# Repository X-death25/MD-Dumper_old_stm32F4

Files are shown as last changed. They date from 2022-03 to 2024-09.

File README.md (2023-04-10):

# MD-Dumper

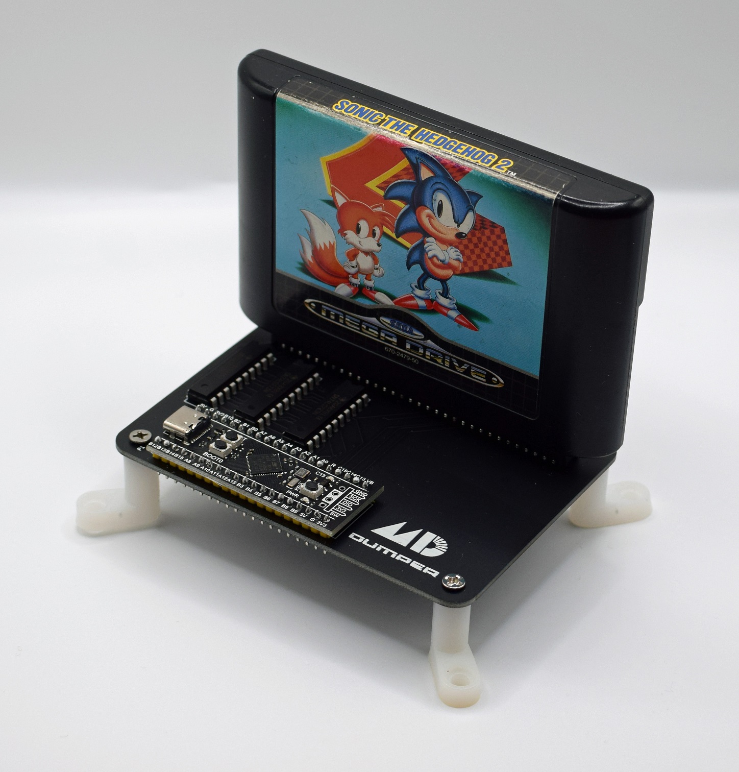
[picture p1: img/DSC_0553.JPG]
MD_pcb
 

What is it ?
-----

MD Dumper is an USB Sega Megadrive cartridge Dumper : <br>
Hardware is based on STM32F4 (BluePillV2) : STM32F4x1 MiniF4 https://github.com/WeActTC/MiniSTM32F4x1  <br>
New version also add some developpement feature witch can be usefull for Megadrive developper.  <br>

Feature :
-----

Firmware Version : 2.0

Software Version : 2.0

| Feature | Implemented |
| --- | --- |
| ROM Dump up to 16 MEG  Classic | :white_check_mark: |
| ROM Dump up to 32 MEG  Bankswitch | :white_check_mark: |
| SRAM Backup Memory Classic | :white_check_mark: |
| SRAM Backup Memory Bankswitch | :white_check_mark: |
| Rewrite Krikzz flashkit cart or compatible  | :white_check_mark: |

How to use it ?
-----

You just need an USB-C to USB. <br>
Connect the dumper to the PC and wait blue led activation. Insert game cartridge.  <br>
Start the software. Enjoy ! <br>

Operating System Compatibility
-----

Microsoft Windows 10

Where i can buy it ?
-----

https://www.tindie.com/products/xdeath/md-dumper-usb-megadrive-cartridge-readerwriter/

Linked Repositories
-----

My other projects related to Megadrive Hardware/Software developpement

-=Python MD-Dumper GUI=-
Easy and multiplateform GUI for MD-Dumper <br>
https://github.com/X-death25/PyMD-Dumper

-=DMC Direct Megadrive Connection=-
SGDK lib for bi-directionnal communication between Megadrive and PC <br>
*Coming Soon*

-=SMD_01=-
Simple 5V TTL 8MB Rewritable cartridge for testing code on real hardware <br>
*Coming Soon*

-=X-Flash=-
Altera EPM240 CPLD based Megadrive cartridge used for advanced research <br>
https://github.com/X-death25/X-Flash

Need Help ?
-----
If you need help or want to improvite or report a bug youre welcome to the official MD Dumper Discord !
https://discord.gg/8AtuA29Dnw

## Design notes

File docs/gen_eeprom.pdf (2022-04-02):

Serial EEPROM emulation

Serial EEPROM devices are present in a few Sega Genesis cartridges and used as external Backup RAM. As you will later see, they can NOT be emulated as usual parallel SRAM and also use various modes depending on their memory size. Most Genesis/Megadrive emulators out there does not emulate those custom devices, resulting in various glitches (beside the fact that saving game data is impossible) in games that rely on this.

Here are some links to datasheets for each kind of EEPROM types for those who couldn’t understand my bad english ;)

### 24C01(mode1) : http://www.icmic.com/datasheets/X24C01.pdf

24C01-24C16(mode2) :

### http://www.atmel.com/dyn/resources/prod_documents/doc0180.pdf

### 24C64 (mode3):http://www.phys.hawaii.edu/~bryce/component_data/24LC65-ISM.pdf

Basically, the protocol used so that the Main CPU (68000), considered as MASTER device, can communicate with the serial EEPROM (considered as SLAVE device), could be summarized this way:

•SLAVE is controlled by the MASTER using two serial lines:

o/SDA is the DATA line, used to send/receive data (READ/WRITE)
o/SCL is the CLOCK line used to manage the clock cycles (WRITE ONLY)

Each line is mapped in the 68000 address space at a specific addres, at one specific bit position (see various used mappers in game database) and can have LOW (bit=0) or HIGH (bit=1) state.

•A clock cycle starts by a transition of /SCL from LOW to HIGH and ends by a transition of /SCL from HIGH to LOW. This is used by the MASTER to indicate when /SDA state refers to a new valid DATA bit (received or sent).

•MASTER and SLAVE devices communicate through 8-bits DATA word, which require 8 clock cycles. The 9th cycle is called the ACK cycle where the receiver (SLAVE or MASTER, depending on the current operation) must send an acknowledge to the sender by setting /SDA line LOW during this cycle, when it is ready to receive more data.

•Each READ or WRITE operation must be initiated by the MASTER with a START condition and terminated with a STOP condition:

oSTART condition is set when /SDA is changed from HIGH to LOW while /SCL remains HIGH
oSTOP condition is set when /SDA is changed from LOW to HIGH while /SCL remains HIGH

•After the START condition, depending on the EEPROM mode, the MASTER immediately send one or more 8-bit words to specify the address that should be later read or written. There are 3 known EEPROM modes:

oMode 1 (24C01 only) have a maximal size of 128bytes (7 bits address) and need only one address word. The 7 first bits set the memory address to be read/write and the 8th bit set the operation type (READ or WRITE)

oMode 2 (24C01 to 24C16) can have up to 8 devices linked together, with a maximal size of 2 Kbytes (11 bits address max.), which means one 24C16, two 24C08, four 24C04 or eight 24C02/24C01 :

the 1st word has 4 fixed bits, then 3bits setting the device address and/or eventually the upper bits of the memory address to read/write (24C04-24C16). The 8th bit set the type of the operation (READ or WRITE).

the 2
nd word set the lower bits of the memory address to read/write (only 7bits for 24C01 in mode 2, because it’s only 128 bytes wide)

oMode 3 (24C32 and more) work like Mode 2 excepted that the maximal address size is 64 Kbytes (max. 16 bits address) per device (a maximum of eight devices can be linked with no size restriction).

the 1st word is like in the previous mode, excepted bits d3-d1 always set the device address (0-7). Last bit always set the operation type.

the 2
nd word set the upper bits of the memory address to read/write (the number of bits depends on the memory size)

the 3rd word set the eight lower bits of the memory address to read/write.

NB: In modes 2 and 3, before a READ operation, only the 1st word is actually sent, the EEPROM contains an address counter that saves the address of the next word to be accessed (incremented from a previous READ or WRITE operation, as stated below)

•After a WRITE operation has been initiated, the MASTER will send one or more 8bits DATA words through the /SDA line. After each written word, the EEPROM must send a ACK and increment the address for the next data word to be written. The address will roll up to base memory address when maximal writepage size has been reached. If the MASTER send a STOP condition, the WRITE operation ends, otherwise the WRITE operation continues to next address.

•After a READ operation has been initiated, the MASTER will read one or more 8bits DATA words through the /SDA line. After each received word, the MASTER will send a ACK and the EEPROM will increment the address of the next data word to be read. The address will roll up to 0 when maximal memory size has been reached. If the MASTER does not send a ACK during the 9th cycle, the READ operation ends and the EEPROM waits for STOP condition, otherwise, the READ operation continues to next address.

This is pretty how eeprom’s access are emulated in Genesis Plus (see eeprom.c for more details). Thanks a lot to 8bitwizard from spriteminds.net forums who initially give me indications about the various EEPROM types and mappers used in Sega Genesis games.

Following is a game database of Sega Genesis games that I found using serial EEPROM, listed by companies (as they usually use specific company mappers).Their specific caracteristics (mappers, mode, size,...) are also mentionned, deducted from various testings.

Feel free to use these informations and my sourcecode in your own project.

EkeEke (July 2007)

ACCLAIM (81)

NBA Jam (UE)(J)

T-081326, T-81033
header OK ($200001-$200001)

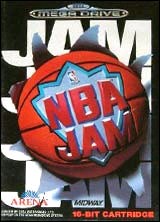
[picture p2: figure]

MODE: 8BITS WORD ADDRESS (MODE2) SIZE_MASK: 0xFF (24C02)
PAGE_MASK: 0x03
SDA_IN : 0x200001 (bit 0)
SDA_OUT: 0x200001 (bit 1)
SCL : 0x200001 (bit 1)

NB: this game uses a different EEPROM mapper than any other Acclaim games. Also it uses 16-bits write & read to access EEPROM.

Blockbuster World Video Game Championship II (U) NBA Jam Tournament Edition (UE)(J)

T-81406, T-81143
header KO

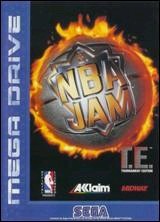
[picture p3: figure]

MODE: 8BITS WORD ADDRESS (MODE2) SIZE_MASK: 0xFF (24C02)
PAGE_MASK: 0x03
SDA_IN : 0x200001 (bit 0)
SDA_OUT: 0x200001 (bit 0)
SCL : 0x200000 (bit 0)

NB: Rev 00 of the game has buggy eeprom support, only Rev01 version will correctly save game data.

NFL Quarterback Club (JUE)

T-081276
header OK ($200000-$200001)

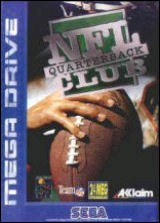
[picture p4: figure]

MODE: 8BITS WORD ADDRESS (MODE2) SIZE_MASK: 0xFF (24C02)
PAGE_MASK: 0x03
SDA_IN : 0x200001 (bit 0)
SDA_OUT: 0x200001 (bit 0)
SCL : 0x200000 (bit 0)

NFL Quarterback Club 96 (UE)

T-081586
header OK ($200000-$200001)

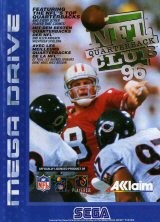
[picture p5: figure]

MODE: 8BITS WORD ADDRESS (MODE2) SIZE_MASK: 0x7FF (24C16)
PAGE_MASK: 0x07
SDA_IN : 0x200001 (bit 0)
SDA_OUT: 0x200001 (bit 0)
SCL : 0x200000 (bit 0)

College Slam (U)

T-81576
header OK ($200001-$200001)

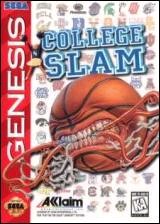
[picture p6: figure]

MODE: 16BITS WORD ADDRESS (MODE3) SIZE_MASK: 0x1FFF (24C64)
PAGE_MASK: 0x07
SDA_IN : 0x200001 (bit 0)
SDA_OUT: 0x200001 (bit 0)
SCL : 0x200000 (bit 0)

Frank Thomas Big Hurt Baseball (UE)

T-81476
header OK ($200000-$200001)

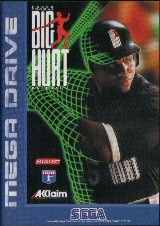
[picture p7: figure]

MODE: 16BITS WORD ADDRESS (MODE3) SIZE_MASK: 0x1FFF (24C64)
PAGE_MASK: 0x07
SDA_IN : 0x200001 (bit 0)
SDA_OUT: 0x200001 (bit 0)
SCL : 0x200000 (bit 0)

ELECTRONIC ARTS (12)

NHLPA Hockey 93 (UE)

T-50396
header KO

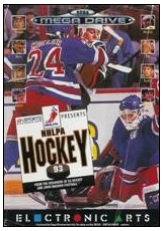
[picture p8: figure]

MODE: 7BITS WORD ADDRESS (MODE1) SIZE_MASK: 0x7F (24C01)
PAGE_MASK: 0x03
SDA_IN : 0x200001 (bit 7)
SDA_OUT: 0x200001 (bit 7)
SCL : 0x200001 (bit 6)

Rings of Power (UE)

T-50176
header KO

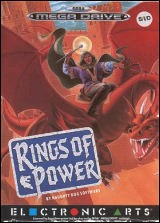
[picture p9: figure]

MODE: 7BITS WORD ADDRESS (MODE1) SIZE_MASK: 0x7F (24C01)
PAGE_MASK: 0x03
SDA_IN : 0x200001 (bit 7)
SDA_OUT: 0x200001 (bit 7)
SCL : 0x200001 (bit 6)

These two games use 16-bits write & read to access EEPROM.

SEGA

Evander 'Real Deal' Holyfield's Boxing (UE)(J)

MK-1215, G-4084
header OK ($200001-$200001)

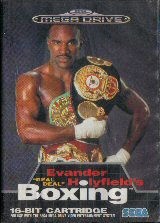
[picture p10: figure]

MODE: 7BITS WORD ADDRESS (MODE1) SIZE_MASK: 0x7F (24C01)
PAGE_MASK: 0x03
SDA_IN : 0x200001 (bit 0)
SDA_OUT: 0x200001 (bit 0)
SCL : 0x200001 (bit 1)

Greatest Heavyweights of the Ring (J)(U)(E)

G-5538, MK-1228, PR-1993
header OK ($200001-$200001)

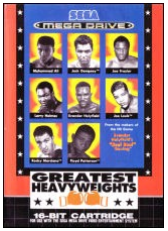
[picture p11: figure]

MODE: 7BITS WORD ADDRESS (MODE1) SIZE_MASK: 0x7F (24C01)
PAGE_MASK: 0x03
SDA_IN : 0x200001 (bit 0)
SDA_OUT: 0x200001 (bit 0)
SCL : 0x200001 (bit 1)

Wonder Boy in Monster World (UE) Wonder Boy V - Monster World III (J)

G-4060
header OK ($200001-$200001)

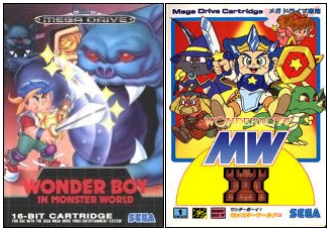
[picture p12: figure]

MODE: 7BITS WORD ADDRESS (MODE1) SIZE_MASK: 0x7F (24C01)
PAGE_MASK: 0x03
SDA_IN : 0x200001 (bit 0)
SDA_OUT: 0x200001 (bit 0)
SCL : 0x200001 (bit 1)

Sports Talk Baseball
00001211-00
header KO

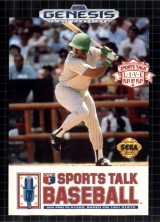
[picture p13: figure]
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

This game uses 16-bits write & read to access EEPROM.

CAPCOM (12)

Megaman - The Wily Wars (E)
Rockman Mega World (J) [alt]

T-12046, T-12053 (checksum = 0xEA80) header OK ($200001-$200001)

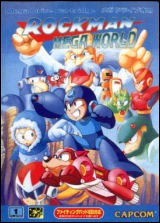
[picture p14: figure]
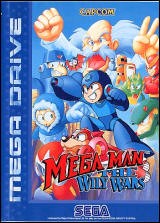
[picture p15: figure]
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

NB: the original version of Rockman Mega World (J) uses traditional SRAM

CODEMASTERS

Micro Machines 2 - Turbo Tournament (E) (J-Cart)

T-120096-50
header KO

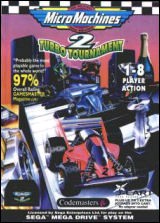
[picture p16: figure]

MODE: 8BITS WORD ADDRESS (MODE2) SIZE_MASK: 0x3FF (24C08)
PAGE_MASK: 0x0F
SDA_IN : 0x300000 (bit 0)
SDA_OUT: 0x380001 (bit 7)
SCL : 0x300000 (bit 1)

NB: this game needs the external RAM to be initialized with 0xFF

Micro Machines Military (E) (J-Cart)

00000000-00 (checksum = 0x168B or 0xCEE0) header KO

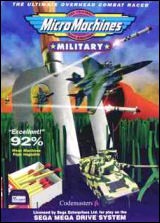
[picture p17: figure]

MODE: 8BITS WORD ADDRESS (MODE2) SIZE_MASK: 0x3FF (24C08)
PAGE_MASK: 0x0F
SDA_IN : 0x300000 (bit 0)
SDA_OUT: 0x380001 (bit 7)
SCL : 0x300000 (bit 1)

Micro Machines Turbo Tournament 96 (E) (J-Cart)

00000000-00 (checksum = 0x165E or 0x2C41) header KO

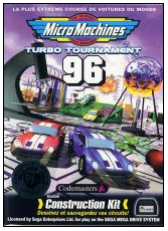
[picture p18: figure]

MODE: 8BITS WORD ADDRESS (MODE2) SIZE_MASK: 0x7FF (24C16)
PAGE_MASK: 0xF
SDA_IN : 0x300000 (bit 0)
SDA_OUT: 0x380001 (bit 7)
SCL : 0x300000 (bit 1)

Brian Lara Cricket 96
Shane Warne Cricket

T-120146-50
header KO

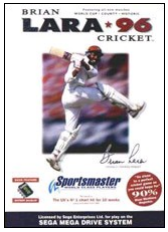
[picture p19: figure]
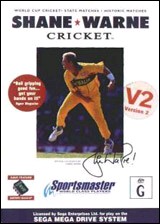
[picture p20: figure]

MODE: 16BITS WORD ADDRESS (MODE3) SIZE_MASK: 0x1FFF (24C64)
PAGE_MASK: ?
SDA_IN : 0x300000 (bit 0)
SDA_OUT: 0x380001 (bit 7)
SCL : 0x300000 (bit 1)

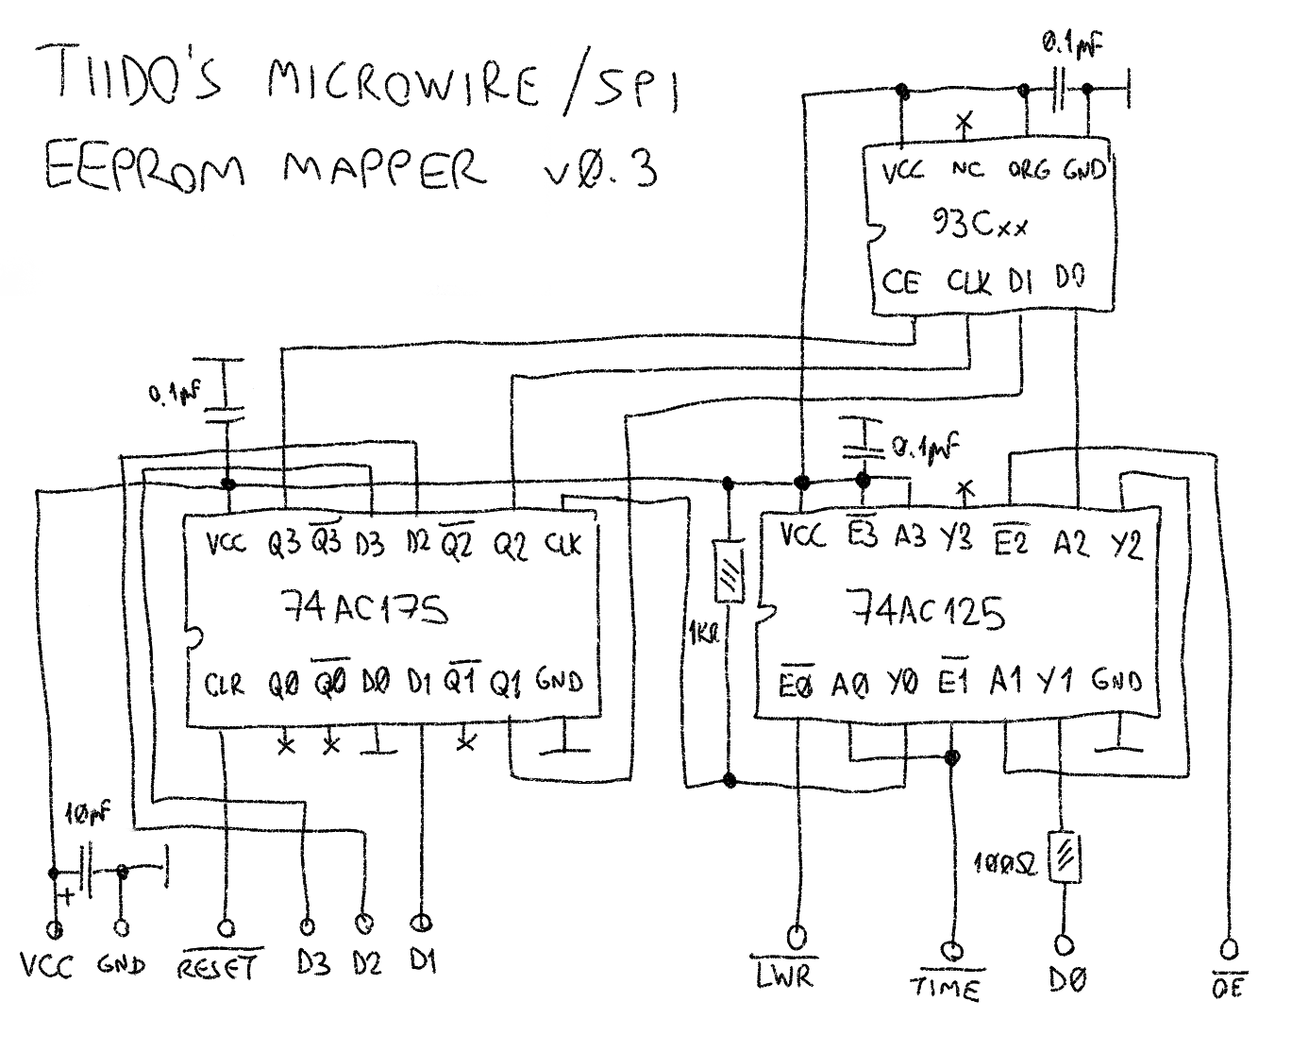
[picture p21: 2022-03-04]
docs/Sega Cartridges/TiidosMicrowireSPImapperForMD.png

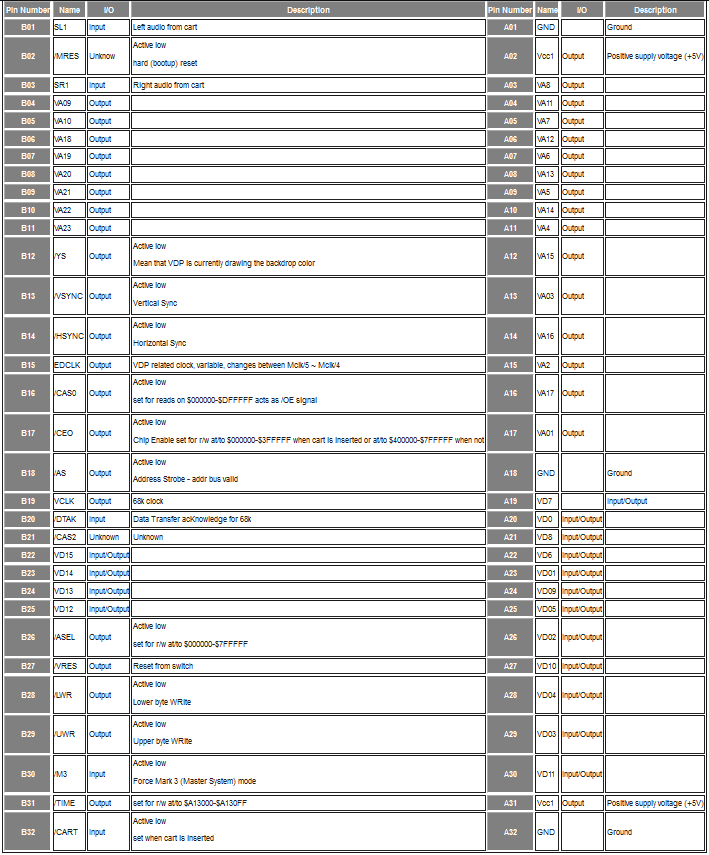
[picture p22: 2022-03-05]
docs/Cartridge Connector MD_Mode.PNG

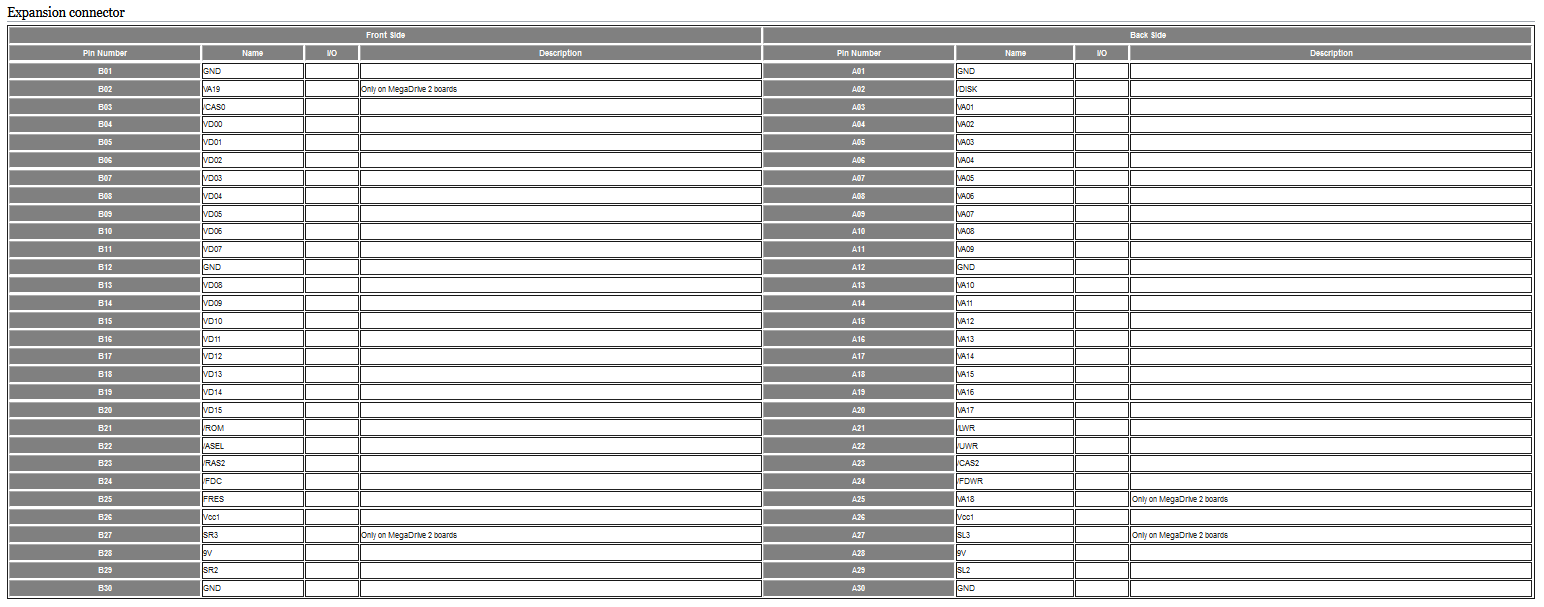
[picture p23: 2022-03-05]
docs/Cartridge Connector EXP_Mode.PNG

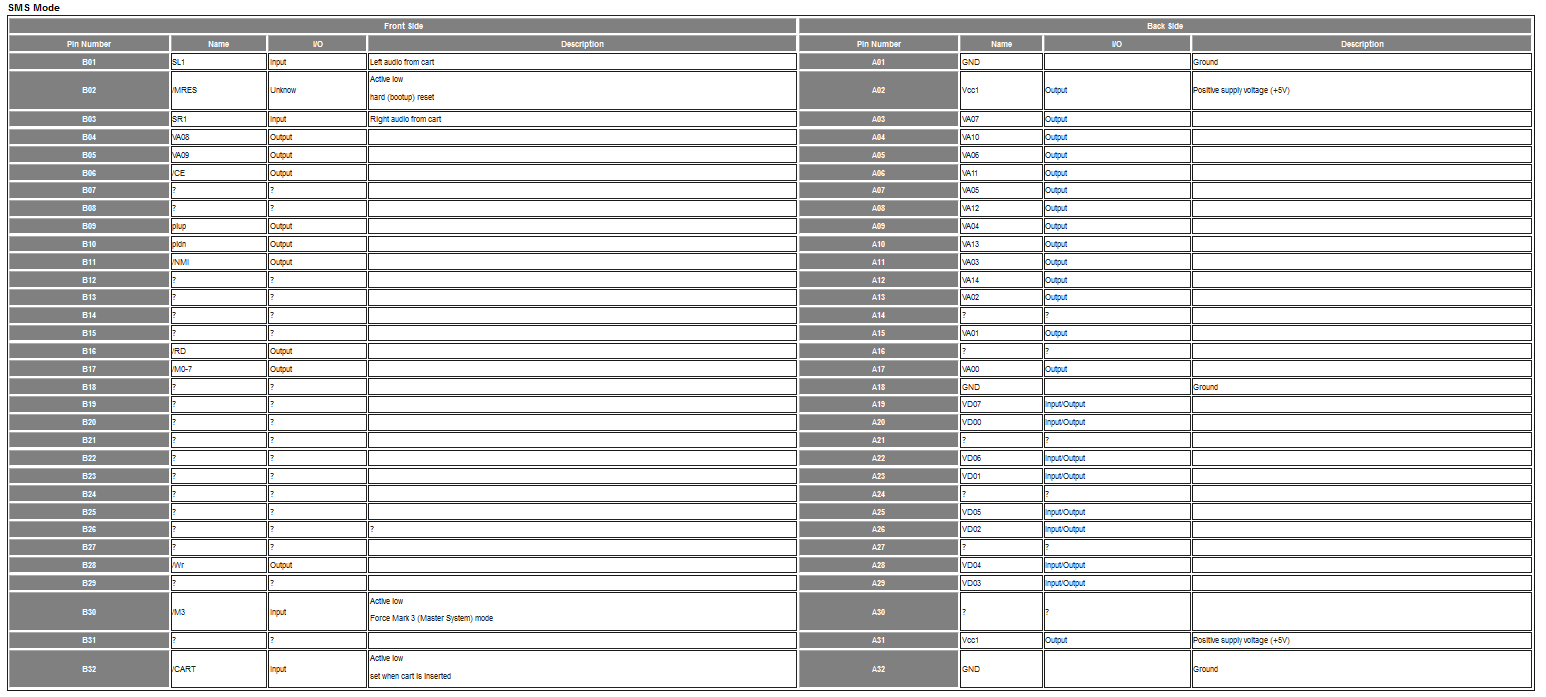
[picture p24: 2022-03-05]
docs/Cartridge Connector SMS_Mode.PNG

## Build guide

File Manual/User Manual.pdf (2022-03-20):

## MD DUMPER

# USB Reader-Flasher Megadrive

F I R S T P U B L I C R E L E A S E 1 2 / 2 0 1 9 | A C T U A L R E L E A S E | V 2 .1 | 0 3 / 2 0 2 2

## Version

2.1

# This product is an unofficial and unlicensed hardware release for the SEGA Mega Drive console, and is not affiliated with SEGA Enterprises Ltd, SEGA

Corporation, or SEGA Holdings Co.

# SEGA® and MEGA DRIVE are trademarks

of SEGA Holdings Co.

# Table of Contents

### Product Feature | 4 Installation | 5

Microsoft Windows | 5
GNU Linux | 6
MAC OS X | 6

### How to Dump your games | 7

Games Meta-Informations | 8
Automatic Mode | 9
Manual Mode | 10

### Save Management | 11

Supported Save type SRAM/Serial EEPROM | 11
Emulator Compatibility | 11
Backup a save from Cartridge to PC | 12
Restore a save from PC to Cartridge | 13

### Flashing an home-made cartridge | 14

Flash Memory Detection | 14
Flash Memory Erase | 15
Flash Memory Write | 16
Extra Hardware Support | 17
Sega Lock-ON | 14
Sega 315-5779 ( Super Street Fighter 2 Classic 40 Meg ) | 14
SSF2 Extended ( Overdrive / Sonic 2 Delta 64 Meg) | 14
SSF2 Full ( Demon Of Asteborg 128 Meg) | 14
Watermelon Mapper | 14
DMC : Direct Megadrive Connection | 14
Firmware Upgrade | 18
Notes | 19

## Chapter

0

1

# Product Feature

## - Read Sega Megadrive cartridge up to 128 Meg

## - Support Bankswitch for ROM & Saves

## - Manage / Backup / Restore your own saves

## - Reflash Third-Party Cartridges

## -Read Master System / Mark III Games

## -Support official Sega Mapper ( SSF2 / Lock-ON / VR)

## -Support Third-Party / Homebrew Mapper

## -Realtime Debug Sega Megadrive <> PC ( DMC )

## -Universal Serial Bus USB-C Power & Use

## -Multi OS compatibility Windows/Linux/Mac

## -Open Source Software

## -Open Source Pyhton GUI

## Chapter

1

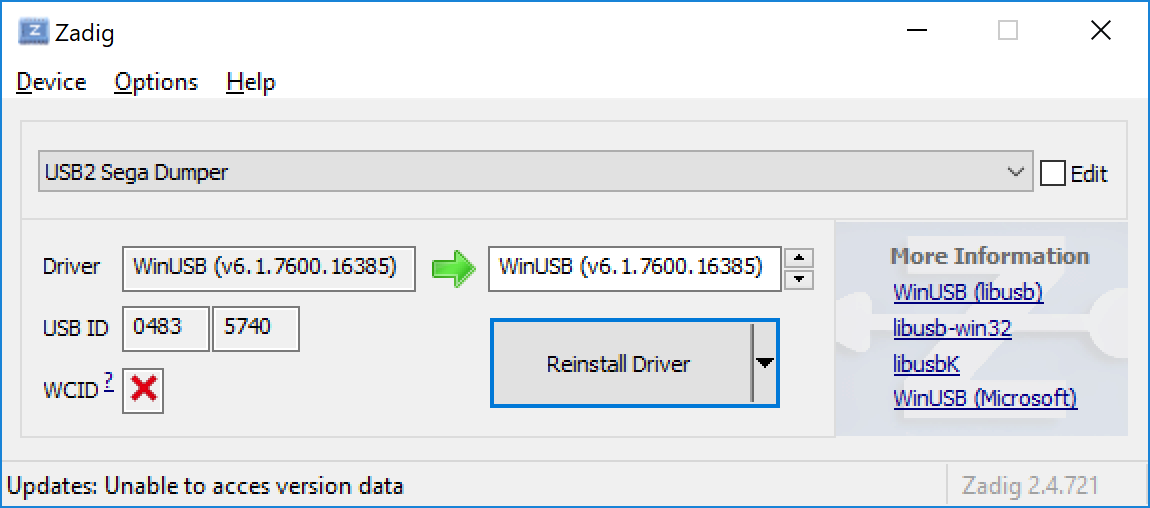
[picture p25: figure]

2

# Installation

## Microsoft Windows :

-Download Lastest release for Windows in the Github (https://github.com/X-death25/MD-Dumper) and extract it in a new or any folder

-Plug the USB Cable

-Wait for Windows automatic hardware installation

-Launch USB View ( in the tools folder)

if everything is ok you should see USB2 Sega Dumper and it's informations

if you see a yellow warning that's mean no driver is currently attached to Sega Dumper so you must use Zadig to force WinUSB driver to Sega Dumper.

https://zadig.akeo.ie/

-After first installation process just do a simple reset by pressing reset button on the board.

-You can launch & use MD Dumper

## Chapter

2

3

## GNU Linux :

-Download Lastest release for Linux in the Github (https://github.com/X-death25/MD-Dumper) and extract it in a new or any folder

-Plug the USB Cable

-You could open a terminal and enter dmesg command for checking installation

if everything is ok you must see these lines

-Enter sudo ./Sega_Dumper for Launch & Use.

## MAC OS X :

/* Todo */

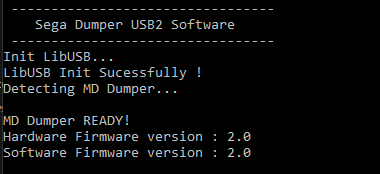
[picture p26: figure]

4

# How to Dump your games

Before dump your game cartridge be sure MD dumper is deconnected and both cartridge slot and game slot is clean.

You can clean it with isopropyl alcohol if needed.

Plug the USB-C to USB cable in the connector and on your PC.

The status led must be following this order :

-RED power led ON

-BLUE access led ON after 3 seconds

When blue led is ON you can insert your game cartridge.

If you put your game cartridge before power on MD dumper you can have some trouble with bus conflict , you can see that with access led blinking.

You can now start MD dumper software.

Both firmware and software version will be displayed at the top in the init hardware sequence.

## Chapter

3

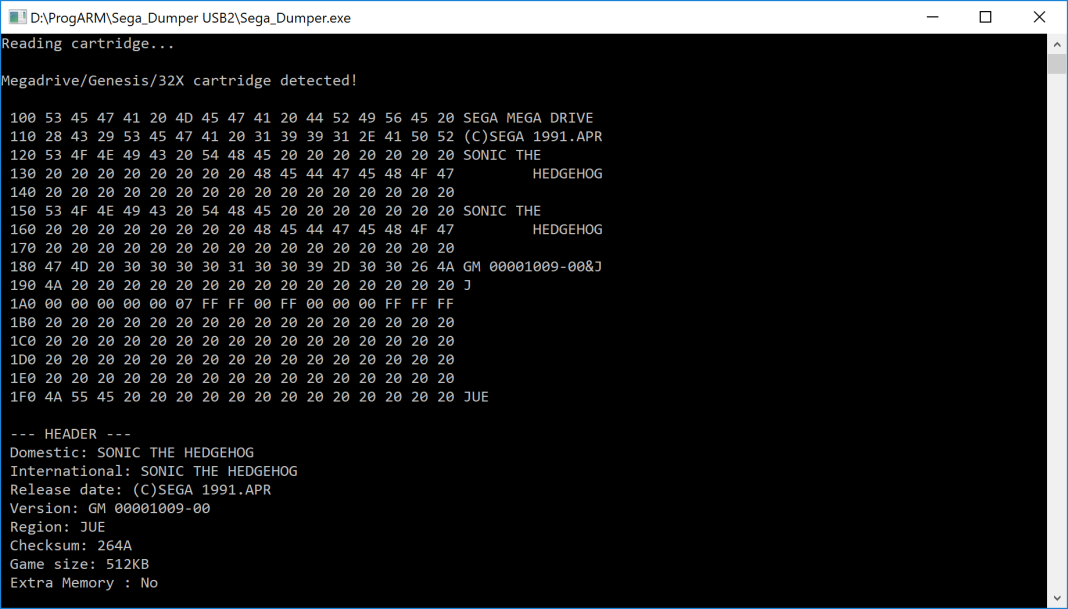
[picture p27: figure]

5

## Games Meta-Informations

The software will start by checking Sega security code and displaying some cartridge informations stored in the beginning of the romchip.

If you cartridge is dirty or damaged Sega security code may not be readed and an error message will be displayed.

The same error message is displayed for a formatted flash cartridge.

In the header parts you can read a summary of all the useful information.
The game and ram size are automatically registered in software so you can use these later for automatic dump mode.
if the game have no backup ram ( like sonic 1 ) you will not see ram info

You can now use the first option of the menu for start a ROM Dump

If you want to read some unofffical games witch don’t use correct information on Metadata you can use the manual dumping mode and specifiy the size of the output dumped file.

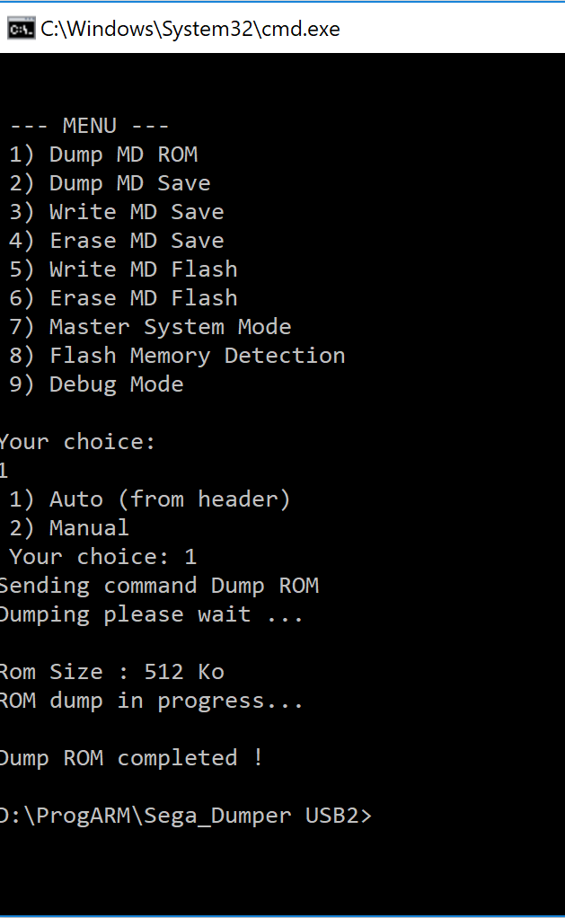
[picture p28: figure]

6

## Dump ( Automatic Mode )

Automatic mode will directly dump the game.
The size of the output file is taken from game meta information.
After dump is completed a file called dump_smd.bin is created.
The created file is generated in an emulator friendly format ( Endianness is reversed ) You can directly launch it in your emulator.

You must reset the board by pressing the push button( reset button) near USB connector for doing another dump ( or unplug – plug the USB )

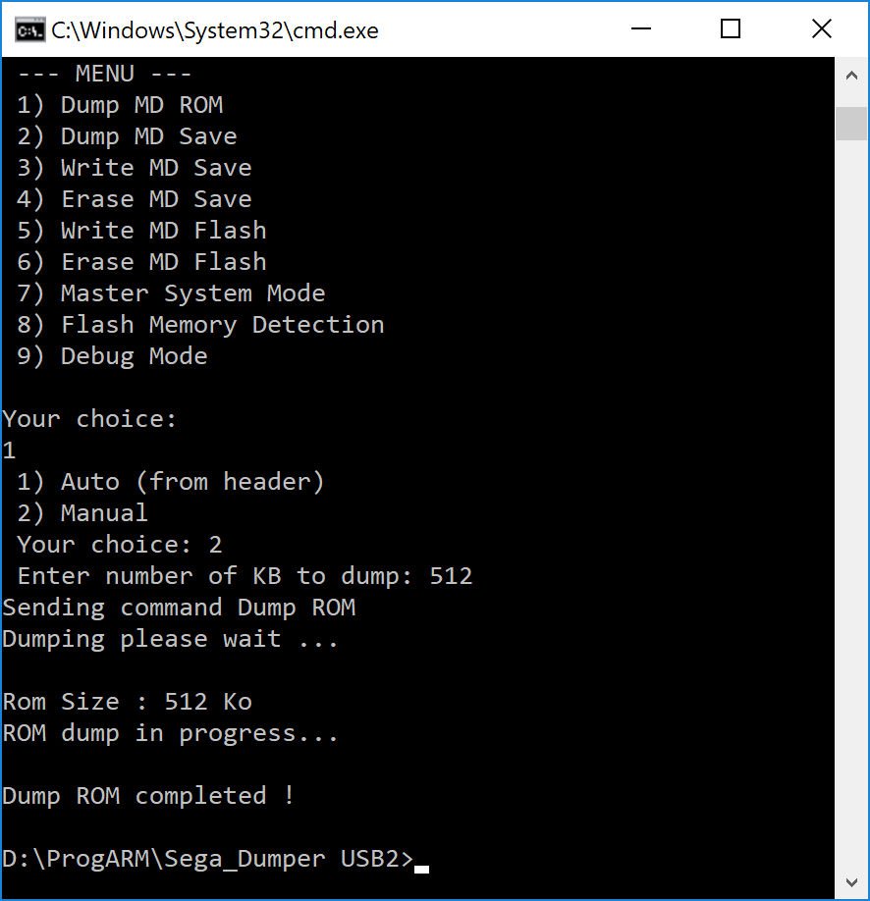
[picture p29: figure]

7

## Dump ( Manual Mode )

Manual mode will dump the game at the specified size.
If the game is smaller than specified size it will be mirrored.
If the game is bigger than specified size you will miss data.
After dump is completed a file called dump_smd.bin is created.

Every official game has correct Meta information so you should only use this mode for homebrew.

MD Dumper support Bankswitch mode so if the game size is more than 16 MEG and have backup ram it will be correctly dumped even in Automatic mode.

8

# SaveManagement

## Supported Save type SRAM / Serial EEPROM

Sega Megadrive cartridge use two different technologies for storing user data

1) Classic parallel 5V SRAM technology + CRC battery for power it when console is turned OFF
- Logic chip for SRAM/ROM access
- CRC Battery
- SRAM chip ( 8k or 32k)
- SRAM power regulator
- ROM chip

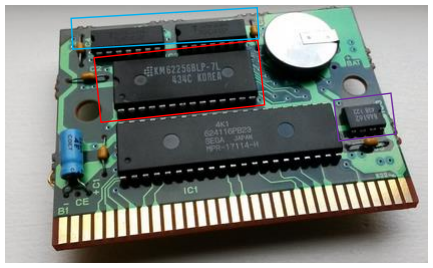
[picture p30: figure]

2) Serial EEPROM I²C/Microwire/SPI
- Logic chip for EEPROM/ROM access
- EEPROM chip
- ROM chip

## Chapter

4

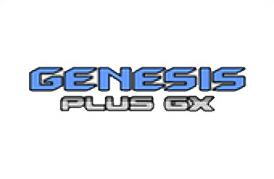
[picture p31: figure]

9

## Emulator Compatibility

The supported emulator is Genesis Plus GX .this emulator has accurate emulation and 100% compatibility even for unofficial games.

You could use your favorite emulator for launch dumped games but the save format used by MD dumper is same as Genesis Plus GX format ( raw 16 bits).

You can start a game in your console , dump the save with MD Dumper and continue your adventure in emulator or reflash your progress in the cartrigde.

Some games use serial EEPROM as backup ram.
You can find a list here :
https://krikzz.com/pub/support/everdrive-md/v2/gen_eeprom.pdf

Reading backup ram for these games has not currently supported. Maybe in a future software upgrade :)

MD Dumper support Bankswitch mode for save too.
Bankswitch ram games will be correctly dumped without modification.

## Backup a save from Cartridge to PC

Insert your cartridge on the edge slot the stickers must be on the front of the PCB.

Start MD Dumper , you will see some save information extracted from header.

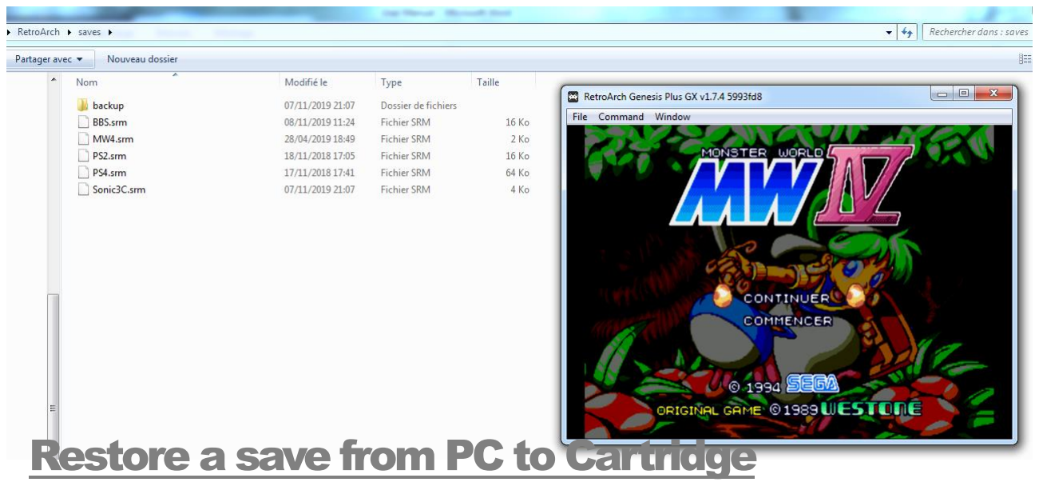
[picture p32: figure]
Restore a save from PC to Cartridge

10

Choose the second menu option : Dump MD Save
like the dump rom option you have multiple dumping mode:

Header information of every official games is correct so you could use automatic mode.
Other mode is for manual mode for specific extra ram size on homebrew PCB. Two files is created :

-dump_smd.srm is the save data in Genesis Plus GX compatible format -raw.srm is an exact dump of the ram chip with no modification.

you just need to copy the dump_smd.srm in the save data of Genesis Plus GX and rename it with the same name of your dumped game.
Forexemple :
MW4.bin for Monster World IV and MW4.srm for save.

Restore or send a save from PC to cartridge is easily as the previous step.

You just need to copy your save file intoMD Dumper folder.

Start MD dumper and choose third option : Write MD Save

write the name of the file with the extension.

for my exemple MW4.srm

ram chip on the cartridge will be fully erased before flash.

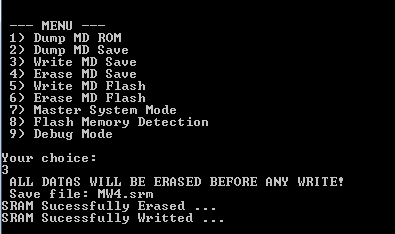
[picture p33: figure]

11

When this step is over you can remove USB cable and plug the cartridge in your console to continue your progress.

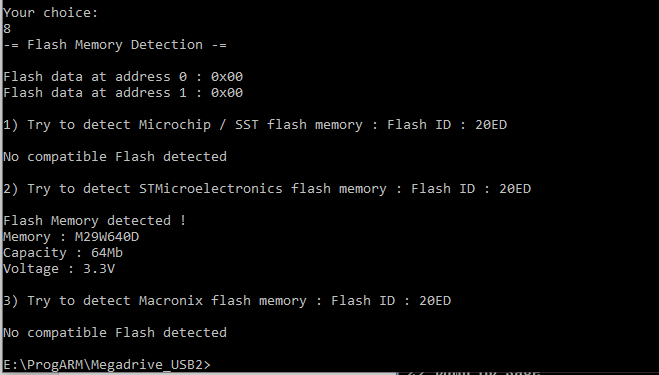
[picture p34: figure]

12

# Flashing an home-made cartridge

## Flash Memory Detection

MD-Dumper support Write Mode for home-made flash based cartridge.

It use the /LWR signal ( pin B28 of the cartridge slot) as /WE signal of flash memory.

First things you could do is try to detect the Manufacturer ID and Chip ID.

Result with M29W640D flash in the Krizz Flash Kit cartridge :

## Chapter

5

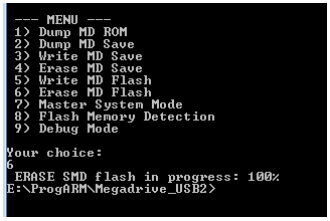
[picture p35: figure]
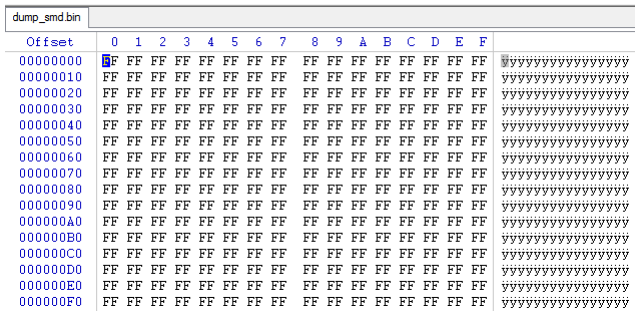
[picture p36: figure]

13

## Flash Memory Erase

Choose option 6 for perform a manually full flash chip Erase.

End of erase will be automatically detected by toggling chip pin.

Time for a complete Erase depends of flash technology (average is less than one minute)

On board Led will be turned "On" when Erase is finished.

MD dumper will check if memory is empty before init a write sequence.

If you dump the flash after an erase you will see only 0xFF bytes/word

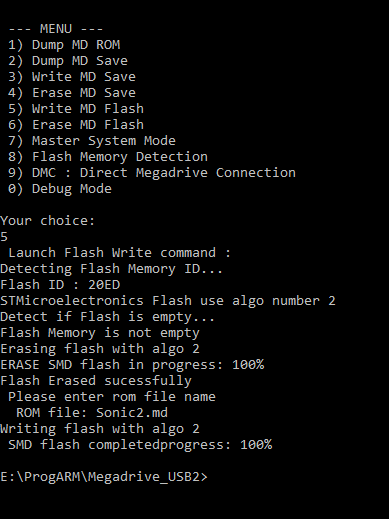
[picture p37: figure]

14

## Flash Memory Write

For sending your game/homebrew copy your file in the same folder of Md dumper

Select option 5 " Write MD Flash " and enter complete name with extension :

1) MD dumper will check if memory is empty before init a write sequence.
2) MD Dumper will check his memory table and select correct flash algo

Speed progress depend of the game size and flash type but average speed is 100 Ko/s.

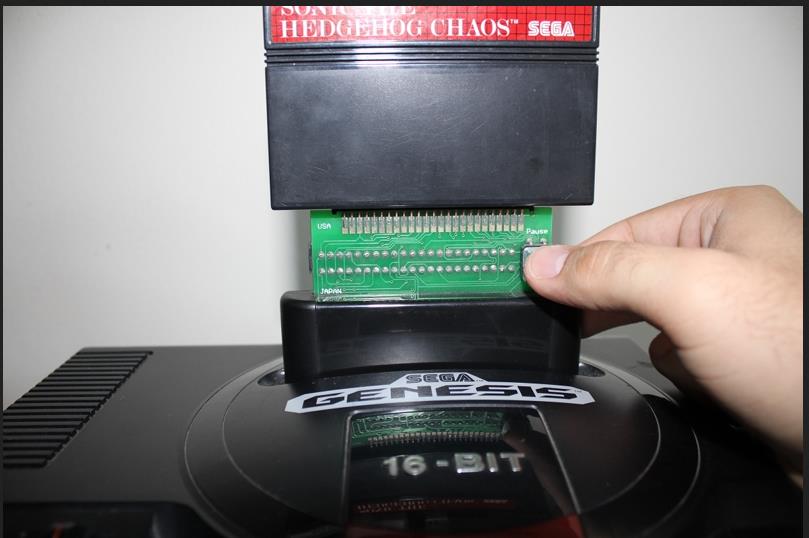
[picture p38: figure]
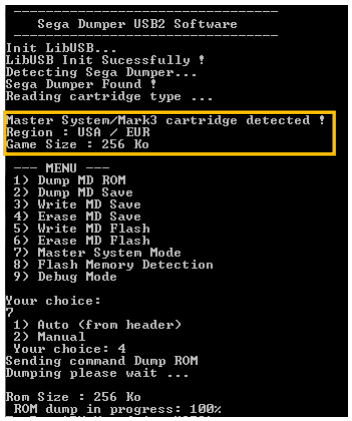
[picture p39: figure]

15

# Master System Compatibility

MD Dumper is also compatible with your Master System / Mark III cartridge.

You can use the Tototek or any compatible Adaptater/Converter.

Just plug the adapter + SMS cartridge and launch MD Dumper you cartridge will be detected directly :

Select option 7 " Master System Mode " and press enter.

After dump is completed a file called dump_sms.sms is created.

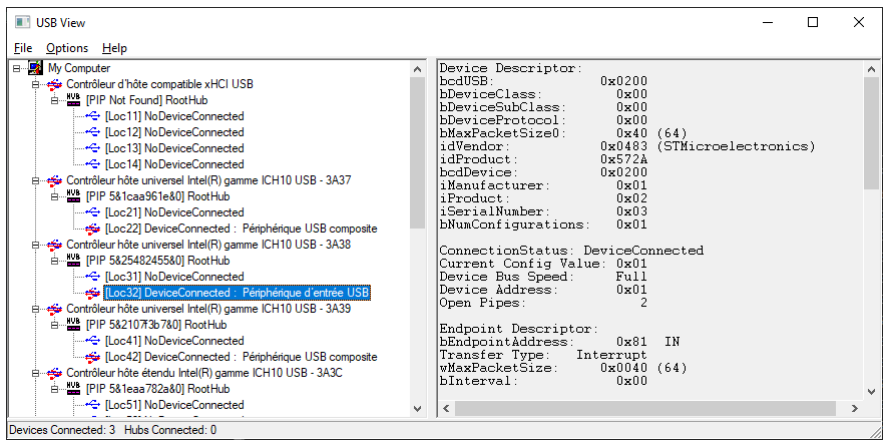
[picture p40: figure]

16

# Firmware Upgrade

MD Dumper New hardware version is based on ARMSTM32F4 so have an embedded bootloader for easy firmware update.

Bootloader is : WeACT HID Bootloader (https://github.com/WeActTC/WeAct_HID_Bootloader_F4x1)

For starting board in update mode you just need to press Keybutton for 2 seconds and press Reset.

Wait 2 seconds, release both button and MD Dumper should start in bootloader mode.

In bootloader mode you can see the LED blinking in progressive mode.

You also can see the USB bootloader mode with Usbview tools

Now you can make a folder with all the file of the Lastest release version in the

MD Dumper Github Firmware Release (https://github.com/X-death25/MD-Dumper/tree/main/Firmware/Lastest)

## Chapter

6

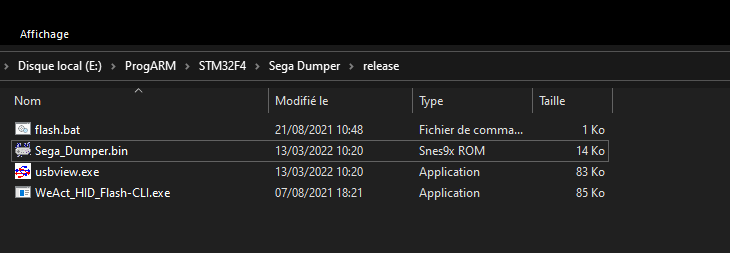
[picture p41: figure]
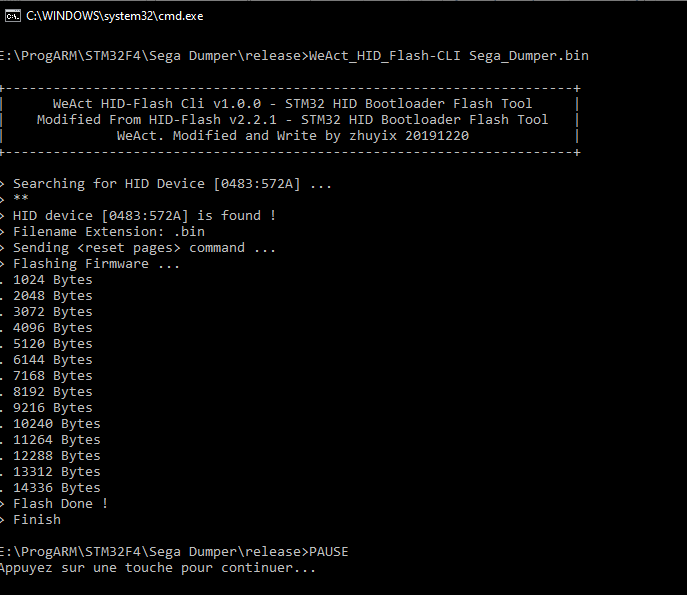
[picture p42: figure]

17

-Sega_Dumper.bin is the ARM compiled code for the STM32

-WeACT_HID_Flash-CLI is bootloader tools for flashing binary

-usbview can help you to view all USB connection of your PC and attached peripherals

-flash.bat is the automatic script for flash binary (call HID flash with Sega_Dumper.bin)

You just need to run cmd script flash.bat :

STM32F4 MD-Dumper code is now successfully updated.

18

# Extra Hardware

## Sega LOCK-ON

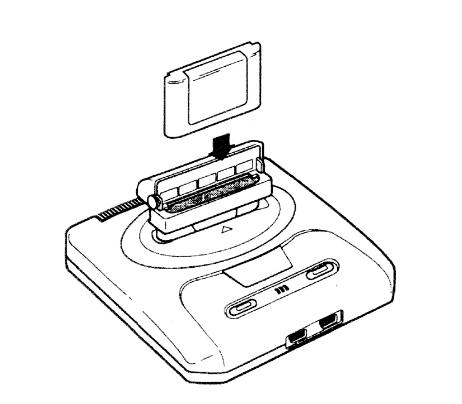
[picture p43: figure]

MD dumper new hardware revision support Sonic & Knuckles SEGA LOCK-ON technology.

Now you can :

-dump Sonic & Knuckles ( Sonic & Knuckles cartridge only)

-dump Blue Sphere ( Sonic & Knuckles + Sonic 1 or Tanglewood)

-dump Sonic 2 & Knuckles ( Sonic & Knuckles + Sonic 2 cartridge)

-dump Sonic 3 & Knuckles ( Sonic & Knuckles + Sonic 3 cartridge)

## Chapter

7

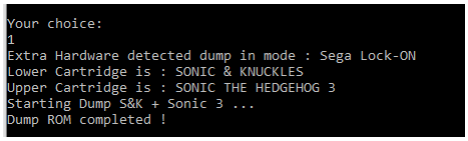
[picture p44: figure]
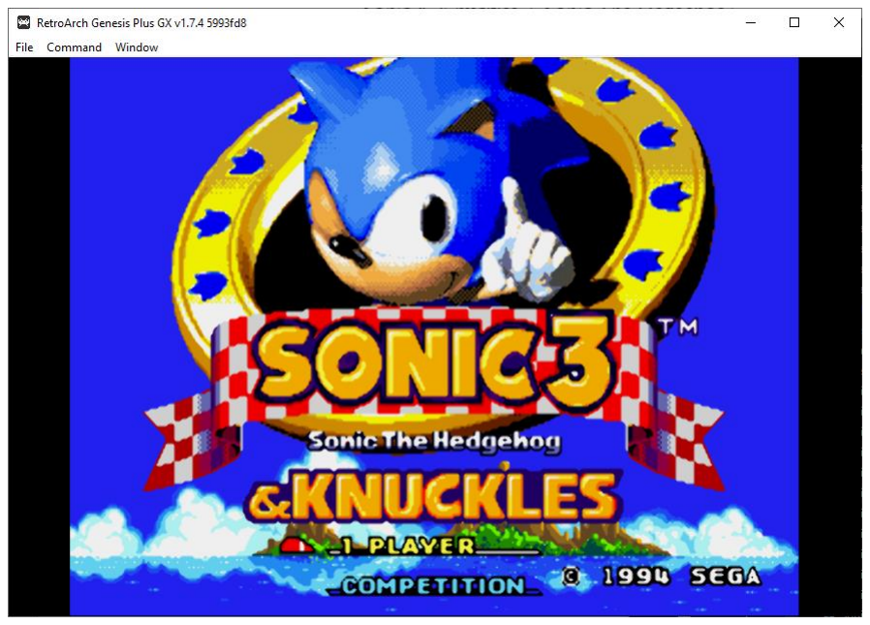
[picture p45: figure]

19

Just select option 1 DUMP ROM and both cartridge UP and LOW should be detected.

If not be sure to clean it properly.

When dump is completed a file will be created in the same folder of Sega Dumper.exe

Possible result is :

Sonic & Knuckles + Sonic The Hedgehog.bin

Sonic & Knuckles + Sonic The Hedgehog2.bin

Sonic & Knuckles + Sonic The Hedgehog3.bin

Be sure to use a compatible emulator for running these game not all emulator support LOCK-ON for storing save.

Note : In the current release ( V2.1) dump save in LOCK-ON mode is not supported yet.

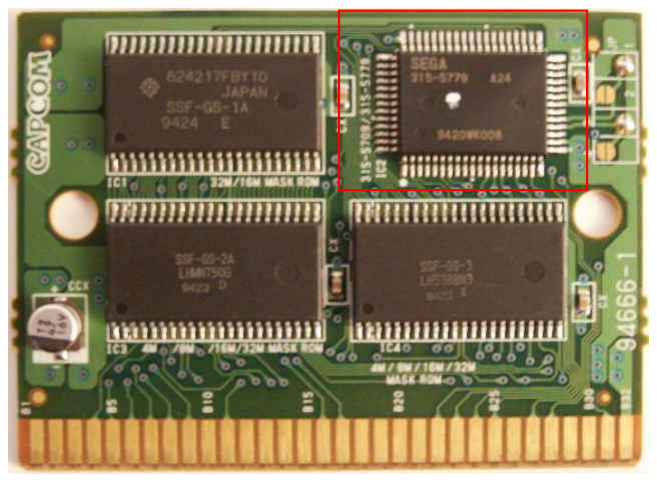
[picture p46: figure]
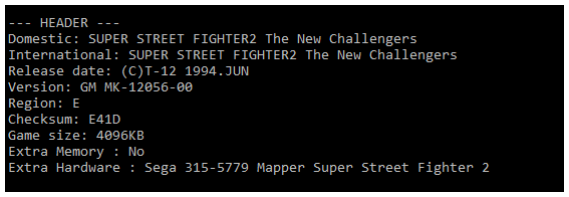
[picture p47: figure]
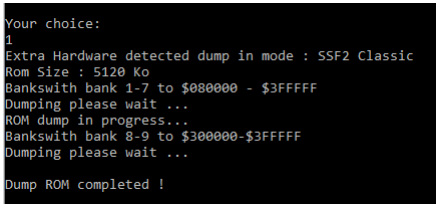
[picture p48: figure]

20

## Sega 315-5779 ( Super Street Fighter 2 )

Sega 315-5779 is the special Sega chip in the game Super Street Fighter 2.

This game use it for store ROM up to 40 Meg.

You can see correct Extra Hardware detection in ROM information:

Header of the game specify a 32Meg cartridge but result is the full 40 Meg data.

Just selection option 1 DUMP ROM and dump will start in SSF2 classic mode

You can find a 40 Meg / 5120 Ko dump_smd.bin ROM Dump

21

## SSF2 Extended

/* To Do*/

Some Homebrew use same bankswitch code as SSF2 for make bigger ROM.

Exemple : Titan Overdrive 2 and Sonic 2 Delta….

MD dumper support this feature, you just need to have SEGA SSF at 0x100 in your rom Header.

22

## SSF2 Full

SSF2 Full is the Sega 315-5779 used at full capacity : 512 Meg ROM + SRAM.

At this time only Demon Of Asterborg use that.

For use MD Dumper in this mode be sure to have SEGA DOA at 0x100

## Virtua Racing

/* To Do*/

## Watermelon Mapper

/* To Do*/

## DMC : Direct Megadrive Connection

/* To Do*/

23

# Release Notes

-13/03/2022 : Add DMC support + Acclaim EEPROM

-18/02/2022 : Second Hardware version release ( ARM STM32F4)

-01/06/2021 : Electronic component shortages -_-‘

-29/12/2019 : First Public Release ( ARM STM32F1 )

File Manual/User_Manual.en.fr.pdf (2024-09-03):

# Version

2.1

# BENNE MD

# Lecteur-Flasher USB Megadrive

PREMIÈRE SORTIE PUBLIQUE 1 2 / 2 0 1 9 | SORTIE RÉELLE | V2. 1 | 0 3 / 2 0 2 2

Traduit de Anglais vers Français - www.onlinedoctranslator.com (https://www.onlinedoctranslator.com/fr/)

# Ce produit est une version matérielle non officielle et sans licence pour la console SEGA Mega Drive, et n'est pas affilié à SEGA

Enterprises Ltd, SEGA.
Corporation, ou SEGA Holdings Co.

# SEGA® et MEGA DRIVE sont des marques

commerciales de SEGA Holdings Co.

0

# Chapitre

# Table des matières

## Caractéristique du produit | 4

# Installation | 5

## Microsoft Windows | 5

## GNU-Linux | 6

## MAC OS X | 6

## Comment vider vos jeux | 7

## Méta-informations sur les jeux | 8 Mode automatique | 9

## Mode manuel | dix

# Gestion des sauvegardes | 11

## Type de sauvegarde pris en charge SRAM/EEPROM série | 11

## Compatibilité de l'émulateur | 11

Sauvegarder une sauvegarde de la cartouche sur le PC | 12

### Restaurer une sauvegarde du PC vers la cartouche | 13

## Flasher une cartouche faite maison | 14

## Détection de mémoire flash | 14

## Effacement de la mémoire flash | 15 Écriture dans la mémoire Flash | 16

## Prise en charge matérielle supplémentaire | 17

## Sega Lock-ON | 14

## Sega 315-5779 ( Super Street Fighter 2 Classic 40 Mo ) | 14 SSF2 étendu (Overdrive / Sonic 2 Delta 64 Mo) | 14 SSF2 complet (Démon d'Asteborg 128 Mo) | 14

## Cartographe de pastèque | 14 DMC : Connexion directe Megadrive | 14 Mise à jour du firmware | 18

## Remarques | 19

1

# Chapitre

# Caractéristique du produit

# - Lire la cartouche Sega Megadrive jusqu'à 128 Mo

## - Prise en charge de Bankswitch pour ROM et sauvegardes

## - Gérer / Sauvegarder / Restaurer vos propres sauvegardes

# - Cartouches Reflash tierces

# - Lire les jeux Master System / Mark III

# - Prise en charge du Sega Mapper officiel (SSF2 / Lock-ON / VR)

# - Prise en charge de tiers/HomebrewMapper

# - Débogage en temps réel Sega Megadrive <> PC (DMC)

## Alimentation et utilisation du bus série universel USB-C

# - Compatibilité multi OS Windows/Linux/Mac

# - Logiciels open source

### - Interface graphique Python Open Source

1

2

# Chapitre

# Installation

# Microsoft Windows :

- Téléchargez la dernière version pour Windows dans leGitHub et extrayez-le (https://github.com/X-death25/MD-Dumper) dans un nouveau ou n'importe quel dossier

### - Branchez le câble USB

### - Attendez l'installation automatique du matériel Windows

## - Lancez USB View (dans le dossier outils)

## si tout va bien, vous devriez voir USB2 Sega Dumper et ses informations

si vous voyez un avertissement jaune, cela signifie qu'aucun pilote n'est actuellement connecté à Sega Dumper, vous devez donc utiliser Zadig pour forcer le pilote WinUSB à Sega Dumper.

## https://zadig.akeo.ie/


- Après le premier processus d'installation, effectuez simplement une simple réinitialisation en appuyant sur le bouton de réinitialisation de la carte.
- Vous pouvez lancer et utiliser MD Dumper

2

# GNU-Linux :

- Téléchargez la dernière version pour Linux dans leGitHub et extrayez-le (https://github.com/X-death25/MD-Dumper) dans un nouveau ou n'importe quel dossier

### - Branchez le câble USB

## - Vous pouvez ouvrir un terminal et entrer la commande dmesg pour vérifier l'installation

## si tout va bien, tu dois voir ces lignes

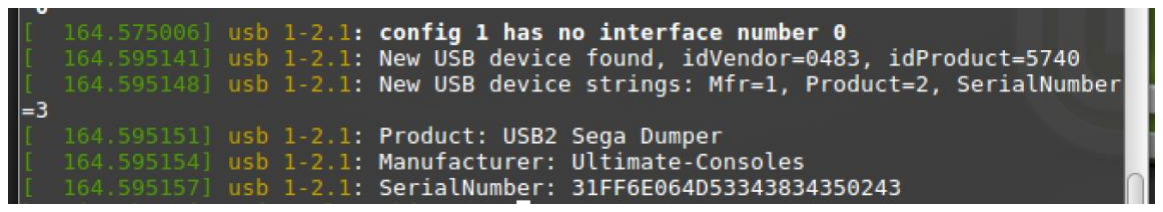
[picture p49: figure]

- Entrez sudo ./Sega_Dumper pour le lancement et l'utilisation.

# MAC OS X :

## /* Faire */

3

3

# Chapitre

# Comment vider vos jeux

Avant de vider votre cartouche de jeu, assurez-vous que le dumper MD est déconnecté et que l'emplacement pour cartouche et l'emplacement de jeu sont propres.

Vous pouvez le nettoyer avec de l'alcool isopropylique si nécessaire.

Branchez le câble USB-C vers USB dans le connecteur et sur votre PC.

## La led d'état doit suivre cet ordre :

- Led d'alimentation ROUGE allumée
- Led d'accès BLEUE ALLUMÉE après 3 secondes

Lorsque la LED bleue est allumée, vous pouvez insérer votre cartouche de jeu.

Si vous mettez votre cartouche de jeu avant d'allumer MD dumper, vous pouvez avoir des problèmes avec un conflit de bus, vous pouvez le voir avec le voyant d'accès clignotant.

Vous pouvez maintenant démarrer le logiciel MD dumper.

La version du micrologiciel et du logiciel sera affichée en haut dans la séquence matérielle d'initialisation.


4

# Méta-informations sur les jeux

Le logiciel commencera par vérifier le code de sécurité Sega et affichera certaines informations sur la cartouche stockées au début du romchip.


Si votre cartouche est sale ou endommagée, le code de sécurité Sega risque de ne pas être lu et un message d'erreur s'affichera.

Le même message d'erreur s'affiche pour une cartouche flash formatée.

Dans les parties d'en-tête, vous pouvez lire un résumé de toutes les informations utiles.
La taille du jeu et de la RAM sont automatiquement enregistrées dans le logiciel afin que vous puissiez les utiliser plus tard pour le mode de vidage automatique.
si le jeu n'a pas de RAM de sauvegarde (comme Sonic 1), vous ne verrez pas d'informations sur la RAM

Vous pouvez maintenant utiliser la première option du menu pour démarrer un ROM Dump

Si vous souhaitez lire des jeux non officiels qui n'utilisent pas d'informations correctes sur les métadonnées, vous pouvez utiliser le mode de vidage manuel et spécifier la taille du fichier vidé en sortie.

5

# Vidage (mode automatique)

Le mode automatique videra directement le jeu.
La taille du fichier de sortie provient des méta-informations du jeu. Une
fois le dump terminé, un fichier appelé dump_smd.bin est créé.
Le fichier créé est généré dans un format convivial pour l'émulateur (l'endianité est inversée). Vous pouvez le lancer directement dans votre émulateur.

Vous devez réinitialiser la carte en appuyant sur le bouton poussoir (bouton de réinitialisation) près du connecteur USB pour effectuer un autre dump (ou débrancher – brancher l'USB).

6

# Vidage (mode manuel)


Le mode manuel videra le jeu à la taille spécifiée. Si le jeu est plus petit que la taille spécifiée, il sera mis en miroir. Si le jeu est plus grand que la taille spécifiée, vous manquerez des données. Une fois le dump terminé, un fichier appelé dump_smd.bin est créé.

Chaque jeu officiel contient des informations méta correctes, vous ne devez donc utiliser ce mode que pour les homebrews.

MD Dumper prend en charge le mode Bankswitch, donc si la taille du jeu est supérieure à 16 MEG et dispose d'une RAM de sauvegarde, il sera correctement vidé même en mode automatique.

7

4

# Chapitre

# SauvegarderGestion

## Type de sauvegarde pris en charge SRAM/EEPROM série

La cartouche Sega Megadrive utilise deux technologies différentes pour stocker les données utilisateur

1) Technologie SRAM parallèle classique 5 V + batterie CRC pour l'alimenter lorsque la console est éteinte

## - Puce logique pour accès SRAM/ROM

## -Batterie CRC

## -Puce SRAM (8k ou 32k)

- Régulateur de puissance SRAM

## - Puce ROM


## 2) Série EEPROM I²C/Microwire/SPI

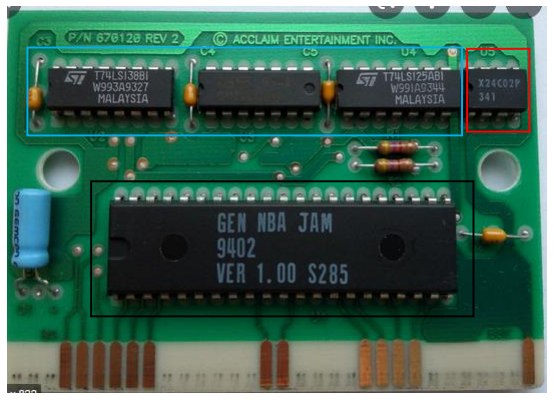
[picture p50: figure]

## - Puce logique pour accès EEPROM/ ROM

## -Puce EEPROM - Puce ROM

8

## Compatibilité de l'émulateur

L'émulateur pris en charge est Genesis Plus GX.cet émulateur a une émulation précise et une compatibilité à 100% même pour les jeux non officiels.


Vous pouvez utiliser votre émulateur préféré pour lancer des jeux dumpés, mais le format de sauvegarde utilisé par MD dumper est le même que le format Genesis Plus GX (16 bits bruts).

Vous pouvez démarrer une partie dans votre console, vider la sauvegarde avec MD Dumper et continuer votre aventure en émulateur ou reflasher votre progression dans la cartouche.

Certains jeux utilisent une EEPROM série comme RAM de sauvegarde.
Vous pouvez trouver une liste ici :

## https://krikzz.com/pub/support/everdrive-md/v2/gen_eeprom.pdf

La lecture de la RAM de sauvegarde pour ces jeux n'est actuellement pas prise en charge. Peut-être dans une future mise à jour du logiciel :)

MD Dumper prend également en charge le mode Bankswitch pour la sauvegarde.
Les jeux RAM Bankswitch seront correctement vidés sans modification.

## Sauvegarder une sauvegarde de la cartouche sur le PC

Insérez votre cartouche sur la fente de bord, les autocollants doivent être sur la face avant du PCB.

Démarrez MD Dumper, vous verrez des informations de sauvegarde extraites de l'en-tête.

9

Choisissez la deuxième option de menu : Dump MD Save
comme l'option dump rom, vous disposez de plusieurs modes de dumping :

Les informations d'en-tête de chaque jeu officiel sont correctes afin que vous puissiez utiliser le mode automatique.

L'autre mode est destiné au mode manuel pour une taille de RAM supplémentaire spécifique sur le PCB
homebrew. Deux fichiers sont créés :
- dump_smd.srm est les données de sauvegarde au format compatible Genesis Plus GX
- raw.srm est un dump exact de la puce RAM sans modification.

il vous suffit de copier le dump_smd.srm dans les données de sauvegarde de Genesis Plus GX et de le renommer avec le même nom que votre jeu dumpé.
Par exemple :
MW4.bin pour Monster World IV et MW4.srm pour la sauvegarde.

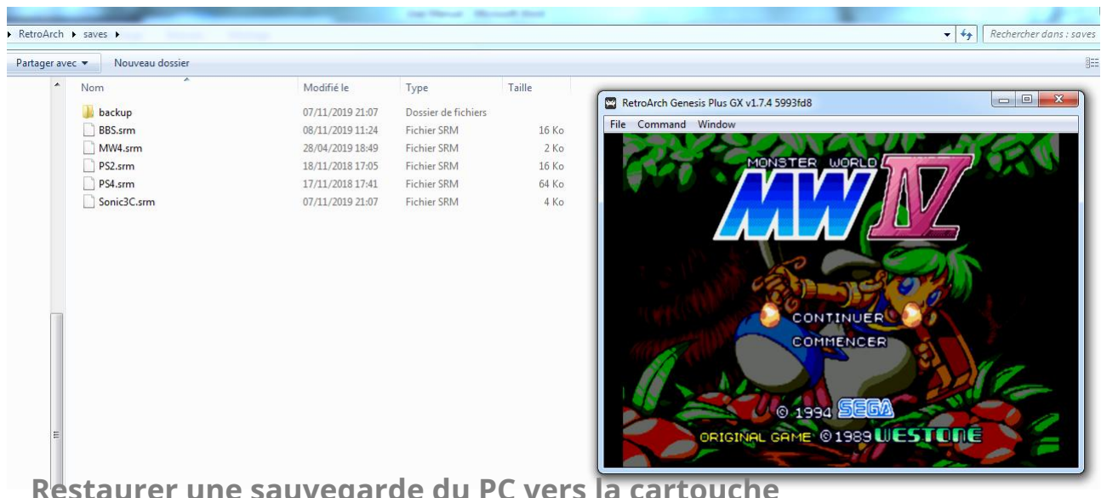
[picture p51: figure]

## Restaurer une sauvegarde du PC vers la cartouche

Restaurer ou envoyer une sauvegarde du PC vers la cartouche est aussi simple que l'étape précédente.

Il vous suffit de copier votre fichier de sauvegarde dans le dossier MD Dumper.

Démarrez MD dumper et choisissez la troisième option : Write MD Save

écrivez le nom du fichier avec l'extension.

pour mon exemple MW4.srm

La puce RAM de la cartouche sera entièrement effacée avant le flash.

dix


Une fois cette étape terminée vous pouvez retirer le câble USB et brancher la cartouche sur votre console pour continuer votre progression.

11

5

# Chapitre

# Flasher un fait maison

# cartouche

# Détection de mémoire flash

MD-Dumper prend en charge le mode d'écriture pour les cartouches flash faites maison.

Il utilise le signal /LWR (broche B28 de l'emplacement de la cartouche) comme signal /WE de la mémoire flash.

La première chose que vous pouvez faire est d’essayer de détecter l’ID du fabricant et l’ID de la puce.

Résultat avec le flash M29W640D dans la cartouche Krizz Flash Kit :


12

## Effacement de la mémoire flash

Choisissez l’option 6 pour effectuer manuellement un effacement complet de la puce flash.

La fin de l'effacement sera automatiquement détectée en basculant la broche de la puce.

Le temps nécessaire à un effacement complet dépend de la technologie du flash (la moyenne est inférieure à une minute)

La LED intégrée sera allumée lorsque l'effacement sera terminé.

MD dumper vérifiera si la mémoire est vide avant de lancer une séquence d'écriture.


Si vous videz le flash après un effacement, vous ne verrez que 0xFF octets/mot


13

## Écriture dans la mémoire flash

Pour envoyer votre jeu/homebrew copiez votre fichier dans le même dossier de Md dumper

Sélectionnez l'option 5 " Write MD Flash " et entrez le nom complet avec l'extension :

1) MD dumper vérifiera si la mémoire est vide avant de lancer une séquence d'écriture.
2) MD Dumper vérifiera sa table de mémoire et sélectionnera l'algo flash correct

La progression en vitesse dépend de la taille du jeu et du type de flash, mais la vitesse moyenne est de 100 Ko/s.

14

# Compatibilité du système maître

MD Dumper est également compatible avec votre cartouche Master System / Mark III.

Vous pouvez utiliser le Tototek ou tout autre adaptateur/convertisseur compatible.


Il suffit de brancher l'adaptateur + la cartouche SMS et de lancer MD Dumper votre cartouche sera détectée directement :


Sélectionnez l'option 7 « Mode système maître » et appuyez sur Entrée.

Une fois le dump terminé, un fichier appelé dump_sms.sms est créé.

15

6

# Chapitre

# Mise à jour du firmware

MD Dumper La nouvelle version matérielle est basée sur ARMSTM32F4 et dispose donc d'un chargeur de démarrage intégré pour une mise à jour facile du micrologiciel.

Le chargeur de démarrage est :Chargeur de démarrage WeACT HID (https://github.com/WeActTC/WeAct_HID_Bootloader_F4x1)

Pour démarrer la carte en mode mise à jour, il vous suffit d'appuyer sur le bouton Key pendant 2 secondes et d'appuyer sur Réinitialiser.

Attendez 2 secondes, relâchez les deux boutons et MD Dumper devrait démarrer en mode bootloader.

En mode bootloader, vous pouvez voir la LED clignoter en mode progressif.

Vous pouvez également voir le mode du chargeur de démarrage USB avec les outils Usbview


Vous pouvez maintenant créer un dossier avec tous les fichiers de la dernière version dans le

Version du micrologiciel MD Dumper Github (https://github.com/X-death25/MD-Dumper/tree/main/Firmware/Lastest)

16


## - Sega_Dumper.bin est le code compilé ARM pour le STM32

- WeACT_HID_Flash-CLI est un outil de démarrage pour flasher le binaire
- usbview peut vous aider à visualiser toutes les connexions USB de votre PC et les périphériques connectés
- flash.bat est le script automatique pour le binaire flash (appelez HID flash avec Sega_Dumper.bin)

Il vous suffit d'exécuter le script cmd flash.bat :


Le code STM32F4 MD-Dumper est maintenant mis à jour avec succès.

17

7

# Chapitre

# Matériel supplémentaire

## Sega VERROUILLAGE

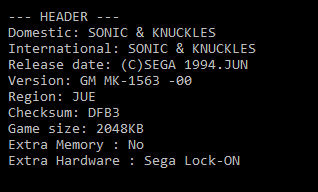
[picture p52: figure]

La nouvelle révision matérielle de MD dumper prend en charge la technologie Sonic & Knuckles SEGA LOCK-ON.

Maintenant vous pouvez :

- dump Sonic & Knuckles (cartouche Sonic & Knuckles uniquement)

## - dump Blue Sphere ( Sonic & Knuckles + Sonic 1 ou Tanglewood)

## - dump Sonic 2 & Knuckles ( Sonic & Knuckles + cartouche Sonic 2)

## - dump Sonic 3 & Knuckles ( Sonic & Knuckles + cartouche Sonic 3)

18

Sélectionnez simplement l’option 1 DUMP ROM et les cartouches UP et LOW devraient être détectées.

Si ce n’est pas le cas, assurez-vous de le nettoyer correctement.

Une fois le dump terminé, un fichier sera créé dans le même dossier que Sega Dumper.exe.

Le résultat possible est :

## Sonic & Knuckles + Sonic The Hedgehog.bin

## Sonic & Knuckles + Sonic The Hedgehog2.bin

## Sonic & Knuckles + Sonic The Hedgehog3.bin

Assurez-vous d'utiliser un émulateur compatible pour exécuter ces jeux, tous les émulateurs ne prennent pas en charge LOCK-ON pour le stockage des sauvegardes.


Remarque : Dans la version actuelle (V2.1), la sauvegarde du dump en mode LOCK-ON n'est pas encore prise en charge.

19

# Sega 315-5779 ( Super Street Fighter 2 )

Sega 315-5779 est la puce Sega spéciale du jeu Super Street Fighter 2.


Ce jeu l'utilise pour stocker une ROM jusqu'à 40 Mo.

Vous pouvez voir la détection correcte du matériel supplémentaire dans les informations ROM :


L'en-tête du jeu spécifie une cartouche de 32 Mo, mais le résultat est la totalité des données de 40 Mo.

Il suffit de sélectionner l'option 1 DUMP ROM et le dump démarrera en mode classique SSF2.


Vous pouvez trouver un Dump ROM dump_smd.bin de 40 Mo / 5120 Ko

20

# SSF2 étendu

## /* Faire*/

Certains Homebrew utilisent le même code de bankswitch que SSF2 pour créer une ROM plus grande.
Exemple : Titan Overdrive 2 et Sonic 2 Delta….

MD dumper prend en charge cette fonctionnalité, il vous suffit d'avoir SEGA SSF à 0x100 dans l'en-tête de votre rom.

21

## SSF2 complet

SSF2 Full est le Sega 315-5779 utilisé à pleine capacité : 512 Meg ROM + SRAM.

Pour le moment, seul Demon Of Asterborg l'utilise.

Pour utiliser MD Dumper dans ce mode, assurez-vous d'avoir SEGA DOA à 0x100

# Virtua Racing

## /* Faire*/

## Cartographe de pastèque

## /* Faire*/

# DMC : Connexion directe Megadrive

## /* Faire*/

22

# Notes de version

### - 13/03/2022 : Ajout du support DMC + Acclaim EEPROM

- 18/02/2022 : Sortie de la deuxième version matérielle (ARM STM32F4)
- 01/06/2021 : Pénurie de composants électroniques -_-'
- 29/12/2019 : Première version publique ( ARM STM32F1 )

23

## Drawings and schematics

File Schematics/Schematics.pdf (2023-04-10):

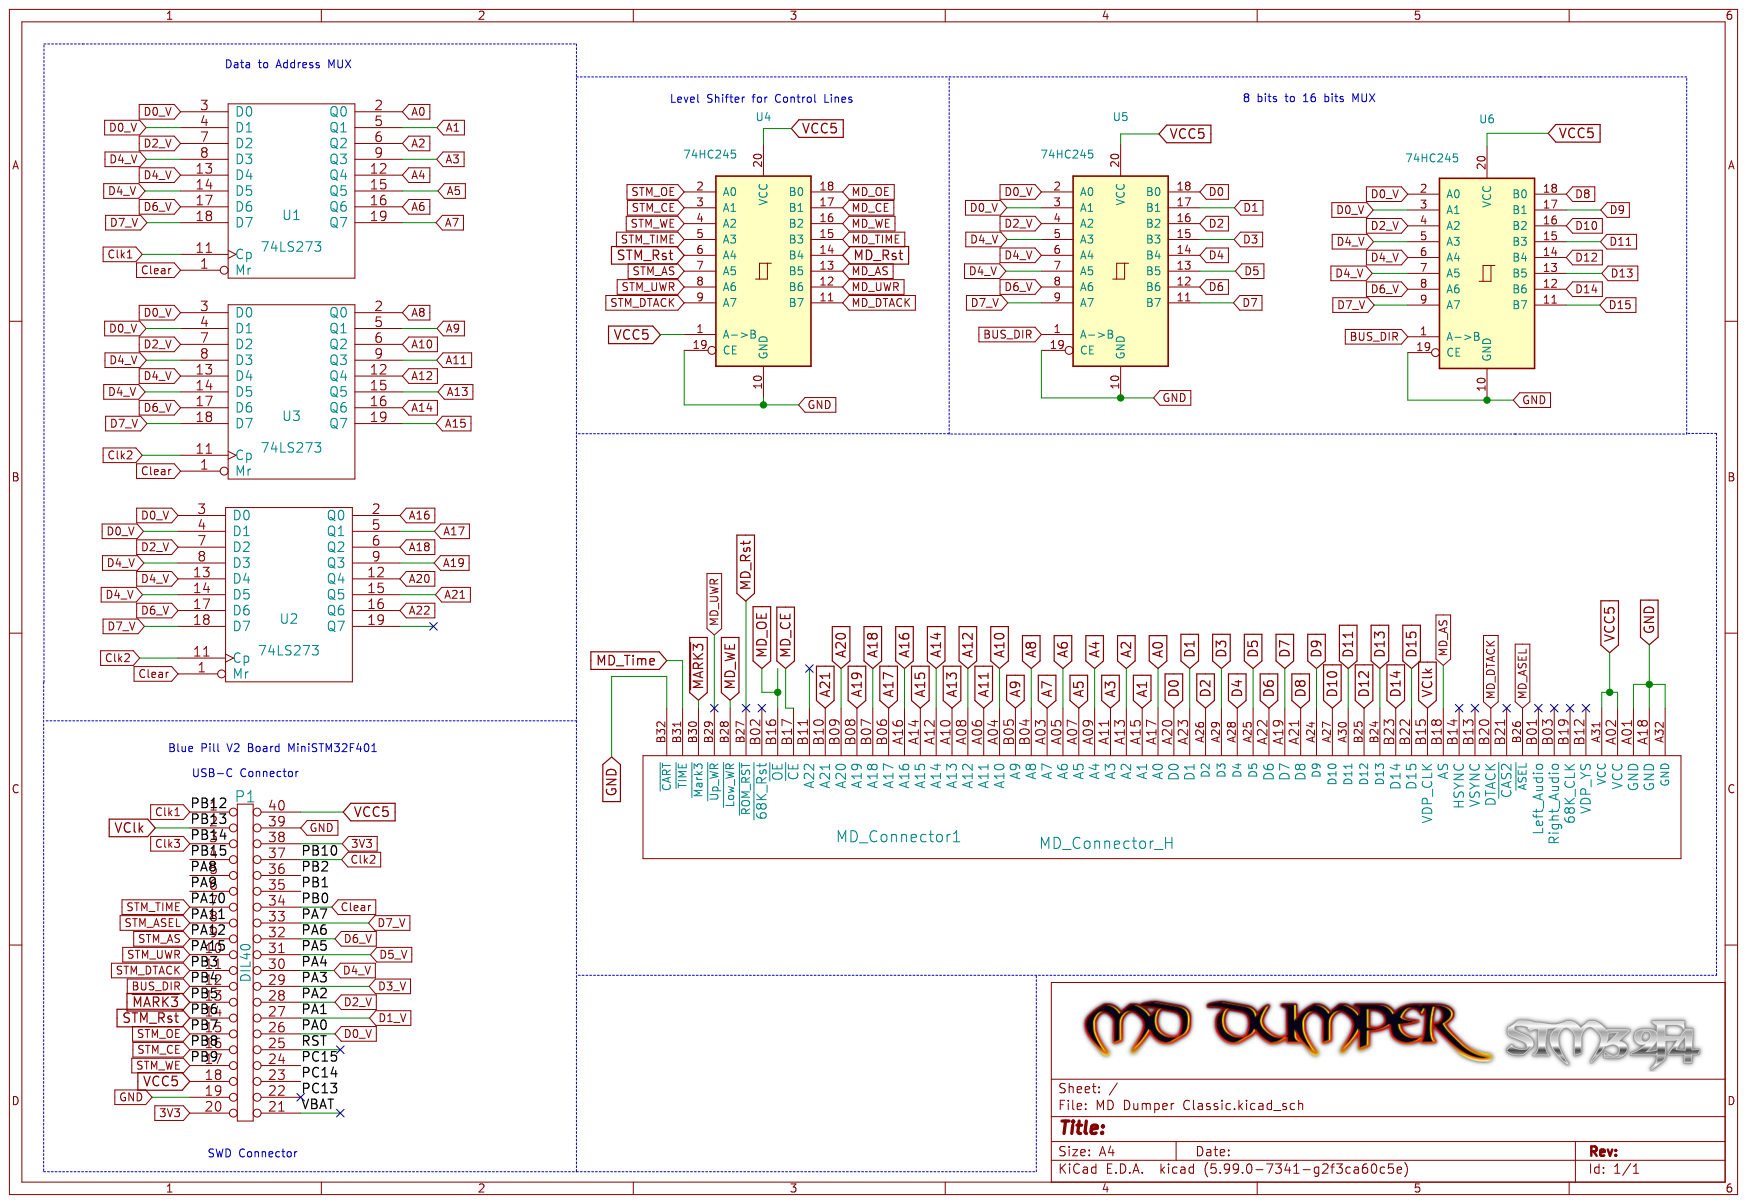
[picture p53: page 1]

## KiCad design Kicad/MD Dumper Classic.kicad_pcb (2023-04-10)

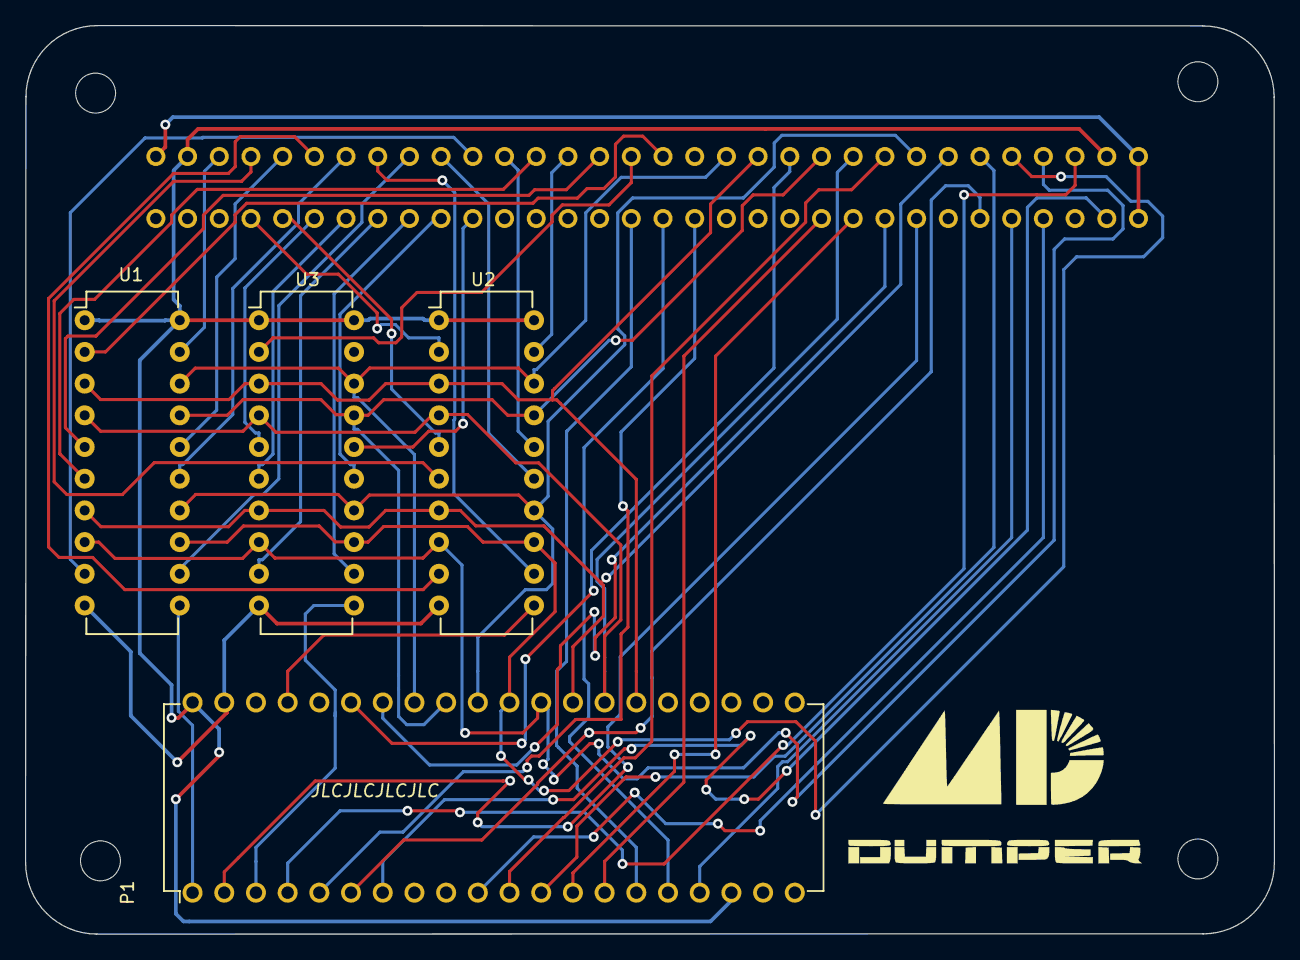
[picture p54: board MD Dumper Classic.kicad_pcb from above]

Board: 2 copper layers, 100.1 x 72.8 mm, 11 parts (0 on the bottom side), 51 nets.

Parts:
Classic 12/2020: MD_Connector_H; MD_Slot
G1: LOGO; logo1
G2: LOGO; logo2
M1, M2, M3, M4: MountingHole_3.2mm_M3
P1: DIL40; STM32
U1, U2, U3: 74LS273; DIP-20_W7.62mm

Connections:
A0: Classic 12/2020.A17 (A0), U1.2 (Q0)
A1: Classic 12/2020.A15 (A1), U1.5 (Q1)
A2: Classic 12/2020.A13 (A2), U1.6 (Q2)
A3: Classic 12/2020.A11 (A3), U1.9 (Q3)
A4: Classic 12/2020.A09 (A4), U1.12 (Q4)
A5: Classic 12/2020.A07 (A5), U1.15 (Q5)
A6: Classic 12/2020.A05 (A6), U1.16 (Q6)
A7: Classic 12/2020.A03 (A7), U1.19 (Q7)
A8: Classic 12/2020.B04 (A8), U2.2 (Q0)
A9: Classic 12/2020.B05 (A9), U2.5 (Q1)
A10: Classic 12/2020.A04 (A10), U2.6 (Q2)
A11: Classic 12/2020.A06 (A11), U2.9 (Q3)
A12: Classic 12/2020.A08 (A12), U2.12 (Q4)
A13: Classic 12/2020.A10 (A13), U2.15 (Q5)
A14: Classic 12/2020.A12 (A14), U2.16 (Q6)
A15: Classic 12/2020.A14 (A15), U2.19 (Q7)
A16: Classic 12/2020.A16, U3.2 (Q0)
A17: Classic 12/2020.B06 (A17), U3.5 (Q1)
A18: Classic 12/2020.B07 (A18), U3.6 (Q2)
A19: Classic 12/2020.B08 (A19), U3.9 (Q3)
A20: Classic 12/2020.B09 (A20), U3.12 (Q4)
A21: Classic 12/2020.B10 (A21), U3.15 (Q5)
A22: Classic 12/2020.B11 (A22), U3.16 (Q6)
Clk1: P1.1, U1.11 (Cp)
Clk2: P1.37, U2.11 (Cp)
Clk3: P1.3, U3.11 (Cp)
D0_V: Classic 12/2020.A20 (D0), P1.26, U1.3 (D0), U2.3 (D0), U3.3 (D0)
D1_V: Classic 12/2020.A23 (D1), P1.27, U1.4 (D1), U2.4 (D1), U3.4 (D1)
D2_V: Classic 12/2020.A26 (D2), U1.7 (D2), U2.7 (D2), U3.7 (D2)
D4_V: Classic 12/2020.A28 (D4), P1.30, U1.13 (D4), U2.13 (D4), U3.13 (D4)
D5_V: Classic 12/2020.A25 (D5), P1.31, U1.14 (D5), U2.14 (D5), U3.14 (D5)
D6_V: Classic 12/2020.A22 (D6), P1.32, U1.17 (D6), U2.17 (D6), U3.17 (D6)
D7_V: Classic 12/2020.A19 (D7), P1.33, U1.18 (D7), U2.18 (D7), U3.18 (D7)
D8: Classic 12/2020.A21 (D8), P1.35
D9: Classic 12/2020.A24 (D9), P1.11
D10: Classic 12/2020.A27 (D10), P1.12
D11: Classic 12/2020.A30 (D11), P1.4
D12: Classic 12/2020.B25 (D12), P1.2
D13: Classic 12/2020.B24 (D13), P1.34
D14: Classic 12/2020.B23 (D14), P1.13
D15: Classic 12/2020.B22 (D15), P1.14
GND: Classic 12/2020.A01 (GND), Classic 12/2020.A18 (GND), Classic 12/2020.A32 (GND), Classic 12/2020.B32 (~CART), P1.19, P1.39, U1.10 (GND), U2.10 (GND), U3.10 (GND)
MD_AS: Classic 12/2020.B18 (AS), P1.5
MD_CE: Classic 12/2020.B17 (~CE), P1.16
MD_OE: Classic 12/2020.B16 (~OE), P1.15
MD_Rst: Classic 12/2020.B27 (~ROM_RST), P1.6
MD_TIME: Classic 12/2020.B31 (~TIME), P1.7
MD_UWR: Classic 12/2020.B29 (~Up_WR), P1.10
MD_WE: Classic 12/2020.B28 (~Low_WR), P1.17
VCC5: Classic 12/2020.A02 (VCC), Classic 12/2020.A31 (VCC), P1.18, P1.40, U1.1 (Mr), U1.20 (VCC), U2.1 (Mr), U2.20 (VCC), U3.1 (Mr), U3.20 (VCC)
d3_v: Classic 12/2020.A29 (D3), U1.8 (D3), U2.8 (D3), U3.8 (D3)

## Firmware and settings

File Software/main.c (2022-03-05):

/*
MD Dumper Software

------------------------------------------------------
V 2.0 03/2022

*Upated Flash algo R/W
*Add Extra Hardware Game Detection
*Add Sega Lock-ON support
*Add SSFII classic support
*Add Pier Solar Support (only dump ROM )
*Preliminary DMC support
------------------------------------------------------
X-death
*/

#include <stdio.h>
#include <stdlib.h>
#include <stdarg.h>
#include <string.h>
#include <ctype.h>
#include <time.h>
#include <math.h>

#include <libusb.h>
#include <assert.h>

#include "s2k.h"

// Specific Win32 lib ( only used for debug )

// #include <conio.h>

// USB Special Command

#define WAKEUP          0x10  // WakeUP for first STM32 Communication
#define READ_MD         0x11
#define READ_MD_SAVE    0x12
#define WRITE_MD_SAVE   0x13
#define WRITE_MD_FLASH 	0x14
#define ERASE_MD_FLASH  0x15
#define READ_SMS   		0x16
#define INFOS_ID        0x18
#define DEBUG_MODE      0x19
#define MAPPER_SSF2     0x20
#define MAPPER_PS   	0x30
#define UNLOCK_PS     	0x31
#define SAVE_BUFFER    	0x41
#define SEND_BUFFER    	0x42
#define WRITE_LOCK_ON  	0x45
#define ENABLE_DMC      0x50
#define DISABLE_DMC     0x51
#define DMC_RESET       0x5A  // Reset DMC communication
#define DMC_DUMP_68KRAM 0x5B  // DMC Dump RAM ( Dump full 68K ram)
#define DMC_READ_BUFFER 0x52  // Read Buffer from MD to PC
#define DMC_SEND_BUFFER 0x53  // Send Buffer from PC to MD


// Version

#define MAX_VERSION 	2
#define MIN_VERSION 	0

// Sega Dumper Specific Variable

char * game_rom = NULL;
char * game_name = NULL;
const char unk[] = {"unknown"};
const char * save_msg[] = {	"WRITE SMD save",  //0
                            "ERASE SMD save"
                          }; //1
const char * wheel[] = { "-","\\","|","/"}; //erase wheel

// Sega Dumper Specific Function

void pause(char const *message)
{
    int c;

    printf("%s", message);
    fflush(stdout);

    while ((c = getchar()) != '\n' && c != EOF)
    {
    }
}

int array_search(unsigned int find, const int * tab, int inc, int tab_size)
{
    int i=0;
    for(i=0; i<tab_size; (i+=inc))
    {
        if(tab[i] == find)
        {
#if defined(DEBUG)
            printf("\n tab:%X find:%X, i:%d, i/inc:%d", tab[i], find, i, (i/inc));
#endif
            return i;
        }
    }
    return -1; //nothing found
}


unsigned int trim(unsigned char * buf, unsigned char is_out)
{

    unsigned char i=0, j=0;
    unsigned char tmp[49] = {0}; //max
    unsigned char tmp2[49] = {0}; //max
    unsigned char next = 1;

    /*check ascii remove unwanted ones and transform upper to lowercase*/
    if(is_out)
    {
        while(i<48)
        {
            if(buf[i]<0x30 || buf[i]>0x7A || (buf[i]>0x29 && buf[i]<0x41) || (buf[i]>0x5A && buf[i]<0x61))
                buf[i] = 0x20; //remove shiiit
            if(buf[i]>0x40 && buf[i]<0x5B)
                buf[i] += 0x20; //to lower case A => a
            i++;
        }
        i=0;
    }

    while(i<48)
    {
        if(buf[i]!=0x20)
        {
            if(buf[i]==0x2F)
                buf[i] = '-';
            tmp[j]=buf[i];
            tmp2[j]=buf[i];
            next = 1;
            j++;
        }
        else
        {
            if(next)
            {
                tmp[j]=0x20;
                tmp2[j]='_';
                next = 0;
                j++;
            }
        }
        i++;
    }

    next=0;
    if(tmp2[0]=='_')
    {
        next=1;    //offset
    }
    if(tmp[(j-1)]==0x20)
    {
        tmp[(j-1)] = tmp2[(j-1)]='\0';
    }
    else
    {
        tmp[j] = tmp2[j]='\0';
    }

    if(is_out)  //+4 for extension
    {
        game_rom = (char *)malloc(j-next +4);
        memcpy((unsigned char *)game_rom, (unsigned char *)tmp2 +next, j-next); //stringed file
    }

    game_name = (char *)malloc(j-next);
    memcpy((unsigned char *)game_name, (unsigned char *)tmp +next, j-next); //trimmed
    return 0;
}

int main()
{

    // LibUSB Specific Var


    int res                      = 0;        /* return codes from libusb functions */
    libusb_device_handle* handle = 0;        /* handle for USB device */
    int kernelDriverDetached     = 0;        /* Set to 1 if kernel driver detached */
    int numBytes                 = 0;        /* Actual bytes transferred. */
    unsigned char usb_buffer_in[64] = {0};   /* 64 byte transfer buffer IN */
    unsigned char usb_buffer_out[64] = {0};  /* 64 byte transfer buffer OUT */
    unsigned long len            = 0;        /* Number of bytes transferred. */

    // Dumper Specific Var

    unsigned long i=0;
    unsigned long j=0;
    unsigned long address=0;
    unsigned long save_address = 0;
    unsigned char *buffer_rom = NULL;
    unsigned char *buffer_save = NULL;
    unsigned char buffer_8b[64];
    unsigned char *buffer_header = NULL;
    unsigned char buffer_system[16];
    unsigned char region[5];
    unsigned char odd=0;
    char *game_region = NULL;
    int choixMenu=0;
    int checksum_header = 0;
    unsigned char manufacturer_id=0;
    unsigned char chip_id=0;
    unsigned short rom_id=0;
    unsigned short flash_id=0;
    unsigned char flash_algo=0;
    unsigned char sms_bank=0;
    unsigned char bank=0;

    // File manipulation Specific Var

    FILE *myfile;
    unsigned char octetActuel=0;

    int game_size=0;
    unsigned long save_size1 = 0;
    unsigned long save_size2 = 0;
    unsigned long save_size = 0;

    // Debug Specific Var

    unsigned char DisplayDebug =0;
    unsigned char Control_Data =0;
    unsigned char Debug_Time =1;
    unsigned char Debug_Asel =1;
    unsigned char Debug_LWR =1;
    char DebugCommand[0];
    unsigned long DebugAddress = 0;
    unsigned long CurrentAddress = 0;
    unsigned short CurrentData = 0xF;
    unsigned char *BufferROM;
    unsigned char *BufferTemp;
    char dump_name[64];
    char empty_flash[512];
    char dump_flash[512];




// Extra Hardware Type

//*****************************************************
// Hardware TYPES
// 0 = No Mapper
// 1 = Sega Virtual Processor SVP Samsung DSP SSP1601
// 2 = Sega 315-5779 Mapper Super Street Fighter 2
// 3 = Sega Lock-on ( Sonic & Knuckles )
// 4 = Extended SSF2 Mapper ( Overdrive 2 / DOA )
// 5 = WaterMelon T-5740 Mapper Pier Solar
//*****************************************************


// Extra Hardware Lookup Table
// Format = {chksum, HardwareType | CartrdigeSize}
// chksum is located in ROM at 0x18E (0xC7)
// Type and Size are combined to conserve memory

    static const unsigned short HardwareID [] =
    {
        0x345D, 0x0102,  // Virtua Racing EUR
        0x95AB, 0x0102,  // Virtua Racing USA
        0x3B99, 0x0102,  // Virtua Racing JAP
        0xE41D, 0x0205,  // Super Street Fighter 2 EUR
        0xE017, 0x0205,  // Super Street Fighter 2 USA
        0xCE25, 0x0205,  // Super Street Fighter 2 JAP
        0xCF50, 0x0205,  // Super Street Fighter 2 USA + hack Stef & Pyron
        0xDFB3, 0x0302,  // Sonic & Knuckles
    };
    unsigned short Hardwaredata=0;
    unsigned char Hardwaretype;
    unsigned long Hardwaresize;



    // Main Program

    printf("\n");
    printf(" ---------------------------------\n");
    printf("    Sega Dumper USB2 Software     \n");
    printf(" ---------------------------------\n");

    printf("Init LibUSB... \n");

    /* Initialise libusb. */

    res = libusb_init(0);
    if (res != 0)
    {
        fprintf(stderr, "Error initialising libusb.\n");
        return 1;
    }

    printf("LibUSB Init Sucessfully ! \n");


    printf("Detecting MD Dumper... \n");

    /* Get the first device with the matching Vendor ID and Product ID. If
     * intending to allow multiple demo boards to be connected at once, you
     * will need to use libusb_get_device_list() instead. Refer to the libusb
     * documentation for details. */

    handle = libusb_open_device_with_vid_pid(0, 0x0483, 0x5740);

    if (!handle)
    {
        fprintf(stderr, "Unable to open device.\n");
        return 1;
    }

    /* Claim interface #0. */

    res = libusb_claim_interface(handle, 0);
    if (res != 0)
    {
        res = libusb_claim_interface(handle, 1);
        if (res != 0)
        {
            printf("Error claiming interface.\n");
            return 1;
        }
    }

// Clean Buffer
    for (i = 0; i < 64; i++)
    {
        usb_buffer_in[i]=0x00;
        usb_buffer_out[i]=0x00;
    }
    i=0;
    for (i = 0; i < 512; i++)
    {
        empty_flash[i]=0xFF;
        dump_flash[i]=0xFF;
    }


// At this step we can try to read the buffer first wake up Sega Dumper

    usb_buffer_out[0] = WAKEUP;// Affect request to  WakeUP Command

    libusb_bulk_transfer(handle, 0x01,usb_buffer_out, sizeof(usb_buffer_out), &numBytes, 0); // Send Packets to Sega Dumper

    libusb_bulk_transfer(handle, 0x82, usb_buffer_in, sizeof(usb_buffer_in), &numBytes, 0);
    /*
    	printf("\nDisplaying USB IN buffer\n\n");
       for (i = 0; i < 64; i++)
        {
            printf("%02X ",usb_buffer_in[i]);
    		j++;
    		if (j==16){printf("\n");j=0;}
        }
    */

    printf("\nMD Dumper %.*s",6, (char *)usb_buffer_in);
    printf("\n");
    printf("Hardware Firmware version : %d", usb_buffer_in[20]);
    printf(".%d\n", usb_buffer_in[21]);
    printf("Software Firmware version : %d",MAX_VERSION);
    printf(".%d\n",MIN_VERSION);

    // while(1);


// Now try to detect cartridge type ( SMS or MD )



    // First try to read ROM MD Header

    buffer_header = (unsigned char *)malloc(0x200);
    i = 0;
    address = 0x80;

    // Cleaning header Buffer
    for (i=0; i<512; i++)
    {
        buffer_header[i]=0x00;
    }

    i = 0;


    while (i<8)
    {

        usb_buffer_out[0] = READ_MD;
        usb_buffer_out[1] = address&0xFF ;
        usb_buffer_out[2] = (address&0xFF00)>>8;
        usb_buffer_out[3]=(address & 0xFF0000)>>16;
        usb_buffer_out[4] = 0; // Slow Mode

        libusb_bulk_transfer(handle, 0x01,usb_buffer_out, sizeof(usb_buffer_out), &numBytes, 60000);
        libusb_bulk_transfer(handle, 0x82,buffer_header+(64*i),64, &numBytes, 60000);
        address+=32;
        i++;
    }


    if(memcmp((unsigned char *)buffer_header,"SEGA",4) == 0)
    {
        printf("\nMegadrive/Genesis/32X cartridge detected!\n");

        for(i=0; i<(256/16); i++)
        {
            printf("\n");
            printf(" %03lX", 0x100+(i*16));
            for(j=0; j<16; j++)
            {
                printf(" %02X", buffer_header[j+(i*16)]);
            }
            printf(" %.*s", 16, buffer_header +(i*16));
        }

        printf("\n");
        printf("\n --- HEADER ---\n");
        memcpy((unsigned char *)dump_name, (unsigned char *)buffer_header+32, 48);
        trim((unsigned char *)dump_name, 0);
        printf(" Domestic: %.*s\n", 48, (char *)game_name);
        memcpy((unsigned char *)dump_name, (unsigned char *)buffer_header+80, 48);
        trim((unsigned char *)dump_name, 0);

        printf(" International: %.*s\n", 48, game_name);
        printf(" Release date: %.*s\n", 16, buffer_header+0x10);
        printf(" Version: %.*s\n", 14, buffer_header+0x80);
        memcpy((unsigned char *)region, (unsigned char *)buffer_header +0xF0, 4);
        for(i=0; i<4; i++)
        {
            if(region[i]==0x20)
            {
                game_region = (char *)malloc(i);
                memcpy((unsigned char *)game_region, (unsigned char *)buffer_header +0xF0, i);
                game_region[i] = '\0';
                break;
            }
        }

        if(game_region[0]=='0')
        {
            game_region = (char *)malloc(4);
            memcpy((char *)game_region, (char *)unk, 3);
            game_region[3] = '\0';
        }

        printf(" Region: %s\n", game_region);

        checksum_header = (buffer_header[0x8E]<<8) | buffer_header[0x8F];
        printf(" Checksum: %X\n", checksum_header);

        game_size = 1 + ((buffer_header[0xA4]<<24) | (buffer_header[0xA5]<<16) | (buffer_header[0xA6]<<8) | buffer_header[0xA7])/1024;
        printf(" Game size: %dKB\n", game_size);



        if((buffer_header[0xB0] + buffer_header[0xB1])!=0x93)
        {
            printf(" Extra Memory : No\n");
        }
        else
        {
            printf(" Extra Memory : Yes ");
            switch(buffer_header[0xB2])
            {
            case 0xF0:
                printf(" 8bit backup SRAM (even addressing)\n");
                break;
            case 0xF8:
                printf(" 8bit backup SRAM (odd addressing)\n");
                break;
            case 0xB8:
                printf(" 8bit volatile SRAM (odd addressing)\n");
                break;
            case 0xB0:
                printf(" 8bit volatile SRAM (even addressing)\n");
                break;
            case 0xE0:
                printf(" 16bit backup SRAM\n");
                break;
            case 0xA0:
                printf(" 16bit volatile SRAM\n");
                break;
            case 0xE8:
                printf(" Serial EEPROM\n");
                break;
            }
            if ( buffer_header[0xB2] != 0xE0 | buffer_header[0xB2] != 0xA0 ) // 8 bit SRAM
            {
                save_size2 = (buffer_header[0xB8]<<24) | (buffer_header[0xB9]<<16) | (buffer_header[0xBA] << 8) | buffer_header[0xBB];
                save_size1 = (buffer_header[0xB4]<<24) | (buffer_header[0xB5]<<16) | (buffer_header[0xB6] << 8) | buffer_header[0xB7];

                save_size = save_size2 - save_size1;
                save_size = (save_size/1024); // Kb format
                save_size=(save_size/2) + 1; // 8bit size
            }
            save_address = (buffer_header[0xB4]<<24) | (buffer_header[0xB5]<<16) | (buffer_header[0xB6] << 8) | buffer_header[0xB7];
            printf(" Save size: %dKb\n", save_size);
            printf(" Save address: %lX\n", save_address);

            if(usb_buffer_in[0xB2]==0xE8) // EEPROM Game
            {
                printf(" No information on this game!\n");
            }
        }
    }


    // Extra Hardware detection Specific code

    // Search checksum cartridge in Custom Hardware game table

    for (i = 0; i < sizeof(HardwareID)/sizeof(short); i++)
    {
        if ( checksum_header == HardwareID[i] )
        {
            Hardwaredata=HardwareID[i+1];
            Hardwaretype = Hardwaredata >> 8;
            Hardwaresize = Hardwaredata & 0x0F;

            if ( Hardwaredata == 0x0302)
            {
                printf(" Extra Hardware : Sega Lock-ON \n");
                game_size=1024*Hardwaresize*1024;
                Hardwaretype = 3;
            }
            if ( Hardwaredata == 0x0205)
            {
                printf(" Extra Hardware : Sega 315-5779 Mapper Super Street Fighter 2 \n");
                game_size=1024*Hardwaresize*1024;
            }
        }
    }
    // Overdrive 2 detection support : https://plutiedev.com/beyond-4mb
    if(memcmp((unsigned char *)buffer_system,"SEGA SSF",8) == 0)
    {
        printf(" Extra Hardware : Extended Sega SSF2 mapper \n");
        game_size=1024*8192;
        Hardwaretype = 4;
    }

    // Pier Solar detection support
    if(memcmp((unsigned char *)dump_name,"PIER SOLAR",10) == 0)
    {
        printf(" Extra Hardware : WaterMelon T-5740 Mapper Pier Solar \n");
        game_size=1024*8192;
        Hardwaretype = 5;
    }

    /*else   // Try to read in SMS mode
    {

    	address = 0x7FF0;
    	usb_buffer_out[0] = READ_SMS;
    	usb_buffer_out[1] = address&0xFF ;
        usb_buffer_out[2] = (address&0xFF00)>>8;
        usb_buffer_out[3]=(address & 0xFF0000)>>16;
        usb_buffer_out[4] = 0; // Slow Mode

        libusb_bulk_transfer(handle, 0x01,usb_buffer_out, sizeof(usb_buffer_out), &numBytes, 0);
    	libusb_bulk_transfer(handle, 0x82, usb_buffer_in, sizeof(usb_buffer_in), &numBytes, 0);



    	if(memcmp((unsigned char *)usb_buffer_in,"TMR SEGA",8) == 0)
    		{
    			printf("\nMaster System/Mark3 cartridge detected !\n");
    			printf("Region : ");
    			if ( usb_buffer_in[15] >> 6 == 0x01 ){ printf("USA / EUR\n");}
    			if ( usb_buffer_in[15] >> 4 == 0x03 ){ printf("Japan\n");}
    			if ( usb_buffer_in[15] >> 4 == 0x03 ){ printf("Japan\n");}
    			game_size = usb_buffer_in[15] & 0xF;
    			//printf("Game Size : %ld Ko \n",game_size);
    			if (game_size == 0x00){ printf("Game Size : 256 Ko");game_size = 256*1024;}
    			if (game_size == 0x01){ printf("Game Size : 512 Ko");game_size = 512*1024;}
    			if (game_size == 0x0c){ printf("Game Size : 32 Ko");game_size = 32*1024;}
    			if (game_size == 0x0e){ printf("Game Size : 64 Ko");game_size = 64*1024;}
    			if (game_size == 0x0f){ printf("Game Size : 128 Ko");game_size = 128*1024;}

    		}*/

    /* 	else
     		{
     			printf(" \nUnknown cartridge type\n(erased flash eprom or bad connection,...)\n");
     		}
    */
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

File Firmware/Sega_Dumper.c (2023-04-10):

/*
------------------------------------------------------
STM32F4 MD Dumper ARM Code
------------------------------------------------------
V2.0 10/04/2023
Public Version

*Upated Flash algo R/W
*Add Extra Hardware Game Detection
*Add Sega Lock-ON support
*Add SSFII classic support

*/

#include <string.h>
#include <stdlib.h>

// include only used LibopenCM3 lib

#include <libopencm3/stm32/rcc.h>
#include <libopencm3/stm32/gpio.h>
#include <libopencm3/usb/usbd.h>
#include <libopencm3/usb/dwc/otg_fs.h>

// MD Dumper Specific Pinout

#define D0 GPIO0   // PA0   MD Data lines
#define D1 GPIO1   // PA1 ok
#define D2 GPIO2   // PA2 ok
#define D3 GPIO3   // PA3 ok
#define D4 GPIO4   // PA4 ok
#define D5 GPIO5   // PA5 ok
#define D6 GPIO6   // PA6 ok
#define D7 GPIO7   // PA7 ok

#define D8 GPIO1   // PB1  ok || WR in DMC Mode
#define D9 GPIO3   // PB3  ok  || RD in DMC Mode
#define D10 GPIO4   // PB4  ok 
#define D11 GPIO15   // PB15  ok
#define D12 GPIO13   // PB13  ok 
#define D13 GPIO0   // PB0  ok 

#define D14 GPIO5   //   PB5 ok
#define D15 GPIO6   //   PB6 ok 

//#define CLK_CLEAR 	GPIO0    // PB0 ok
#define CLK1 		GPIO12   // PB12 ok
#define CLK2 		GPIO10   // PB10 ok
#define CLK3 		GPIO14   // PB14 ok

#define OE 			GPIO7  // PB7 ok 
#define CE 			GPIO8  // PB8 ok
#define WE 			GPIO9  // PB9 ok 
#define RST			GPIO9  // PA9 ok
//#define MARK3 		GPIO5  // PB5 ok  voir pour remplacer par PA9

#define UWR			GPIO15  // PA15 ok 
#define TIME 		GPIO10  // PA10 ok  
#define ASTRB 		GPIO8  // PA8 ok   

#define LED_PIN 	GPIO13 // PC13  STM32 Led

// MD Dumper Special Command

#define WAKEUP     		0x10
#define READ_MD         0x11
#define READ_MD_SAVE  	0x12
#define WRITE_MD_SAVE 	0x13
#define WRITE_MD_FLASH 	0x14
#define ERASE_MD_FLASH 	0x15
#define READ_SMS   		0x16
#define CFI_MODE   		0x17
#define INFOS_ID 		0x18
#define DEBUG_MODE 		0x19


// Version

#define MAX_VERSION 	2
#define MIN_VERSION 	0


//void CheckVIO(void);

// MD Dumper Specific VAR

static const unsigned char stmReady[] = {'R','E','A','D','Y','!'};
static unsigned char dump_running = 0;
static unsigned char read8 = 0;
static unsigned char result=0;
static unsigned int read16 = 0;
static unsigned long address = 0;
static uint32_t len=0;
static uint32_t k=0;
static unsigned int chipid = 0;
static unsigned int slotRegister = 0; //for SMS
static unsigned int slotAdr = 0; //for SMS
static uint32_t gpioreg_inputA=0;
static uint32_t gpioreg_inputB=0;
static uint32_t gpioreg_outputA=0;
static uint32_t gpioreg_outputB=0;


// USB Specific VAR

static char serial_no[25];
static uint8_t usb_buffer_IN[64];
static uint8_t usb_buffer_OUT[64];
uint8_t usbd_control_buffer[128];
//static const unsigned char stmReady[] = {'R','E','A','D','Y','!'};

// MD Dumper function prototype

void wait(long nb);
void setDataInput(void);
void setDataOutput(void);
void DirectWrite8(unsigned char val);
void DirectWrite16(unsigned short val);
void setAddress(unsigned long adr);
void DirectRead8(void);
void DirectRead16(void);
void readMd(void);
void sms_mapper_register(unsigned char slot);
void readSMS(void);
void SendNextPaquet(usbd_device *usbd_dev, uint8_t ep);
void SendARMBuffer(usbd_device *usbd_dev, uint8_t ep);
void readMdSave(void);
void EraseMdSave(void);
void writeMdSave(void);
void writeFlash16(int adr,unsigned short word);
void ResetFlash(void);
void CFIWordProgram(void);
void commandMdFlash(unsigned long adr, unsigned int val);
void reset_command(void);
void EraseFlash(void);
void EraseFlash2(void);
void writeMdFlash(void);
void infosId(void);


//  USB Specific Fonction /////

static const struct usb_device_descriptor dev =
{
    .bLength = USB_DT_DEVICE_SIZE,
    .bDescriptorType = USB_DT_DEVICE,
    .bcdUSB = 0x0200,
    .bDeviceClass = 0xff,
    .bDeviceSubClass = 0,
    .bDeviceProtocol = 0,
    .bMaxPacketSize0 = 64,
    .idVendor = 0x0483,
    .idProduct = 0x5740,
    .bcdDevice = 0x0200,
    .iManufacturer = 1,
    .iProduct = 2,
    .iSerialNumber = 3,
    .bNumConfigurations = 1,
};

static const struct usb_endpoint_descriptor data_endp[] = {{
        .bLength = USB_DT_ENDPOINT_SIZE,
        .bDescriptorType = USB_DT_ENDPOINT,
        .bEndpointAddress = 0x01,
        .bmAttributes = USB_ENDPOINT_ATTR_BULK,
        .wMaxPacketSize = 64,
        .bInterval = 1,
    }, {
        .bLength = USB_DT_ENDPOINT_SIZE,
        .bDescriptorType = USB_DT_ENDPOINT,
        .bEndpointAddress = 0x82,
        .bmAttributes = USB_ENDPOINT_ATTR_BULK,
        .wMaxPacketSize = 64,
        .bInterval = 1,
    }
};

static const struct usb_interface_descriptor data_iface[] = {{
        .bLength = USB_DT_INTERFACE_SIZE,
        .bDescriptorType = USB_DT_INTERFACE,
        .bInterfaceNumber = 1,
        .bAlternateSetting = 0,
        .bNumEndpoints = 2,
        .bInterfaceClass = 0xff,
        .bInterfaceSubClass = 0,
        .bInterfaceProtocol = 0,
        .iInterface = 0,

        .endpoint = data_endp,
    }
};

static const struct usb_interface ifaces[] = {{
        .num_altsetting = 1,
        .altsetting = data_iface,
    }
};

static const struct usb_config_descriptor config =
{
    .bLength = USB_DT_CONFIGURATION_SIZE,
    .bDescriptorType = USB_DT_CONFIGURATION,
    .wTotalLength = 0,
    .bNumInterfaces = 1,
    .bConfigurationValue = 1,
    .iConfiguration = 0,
    .bmAttributes = 0x80,
    .bMaxPower = 0x32,

    .interface = ifaces,
};

static void usb_setup(void)
{
    /* Enable clocks for USB */

    rcc_periph_clock_enable(RCC_OTGFS);

    // Cleaning USB Buffer

    int i=0;

    for(i = 0; i < 64; i++)
    {
        usb_buffer_IN[i]=0x00;
        usb_buffer_OUT[i]=0x00;
    }
}

static const char *usb_strings[] =
{
    "Sege4ever 2021",
    "MD Dumper STM32F4",
    serial_no,
};

static char *get_dev_unique_id(char *s)
{
    volatile uint8_t *unique_id = (volatile uint8_t *)0x1FFFF7E8;
    int i;

    // Fetch serial number from chip's unique ID
    for(i = 0; i < 24; i+=2)
    {
        s[i] = ((*unique_id >> 4) & 0xF) + '0';
        s[i+1] = (*unique_id++ & 0xF) + '0';
    }
    for(i = 0; i < 24; i++)
        if(s[i] > '9')
            s[i] += 'A' - '9' - 1;

    return s;
}


void SendNextPaquet(usbd_device *usbd_dev, uint8_t ep)
{
	
    unsigned char adr = 0;
    unsigned char adr16 = 0;
	
	gpio_set(GPIOA,TIME);
	
    while(adr<64)  // 64bytes/32word
    {
        setDataOutput();
        setAddress(address+adr16); //4,96µs
        setDataInput();

		gpio_clear(GPIOB,CE);
		gpio_clear(GPIOB,OE);
	

        wait(16);

        DirectRead16(); //save into read16 global
        usb_buffer_OUT[adr] = (read16 >> 8)&0xFF; //word to byte
        usb_buffer_OUT[(adr+1)] = read16 & 0xFF;

		gpio_set(GPIOB,OE);
		gpio_set(GPIOB,CE);
	


        adr+=2;  //buffer
        adr16++; //md adr word
  }
    
    usbd_ep_write_packet(usbd_dev,ep,usb_buffer_OUT,64);
    address += 32;
    len +=32;
    
}
 

/*
* This gets called whenever a new IN packet has arrived from PC to STM32
 */
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

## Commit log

2023-04-10 Release Schematics to public version
2023-04-10 Add gerber to public version
    [MD Dumper Classic-B_Cu.gbr, MD Dumper Classic-B_Mask.gbr, MD Dumper Classic-B_Paste.gbr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]
2023-04-10 Release Kicad PCB File to public version
    [MD Dumper Classic.dsn, MD Dumper Classic.kicad_pcb, MD Dumper Classic.kicad_sch]
